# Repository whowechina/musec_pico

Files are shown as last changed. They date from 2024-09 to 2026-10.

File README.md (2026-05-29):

# Musec Pico - MUSECA Style Mini Controller
[点这里可以切换到中文版](README_CN.md)

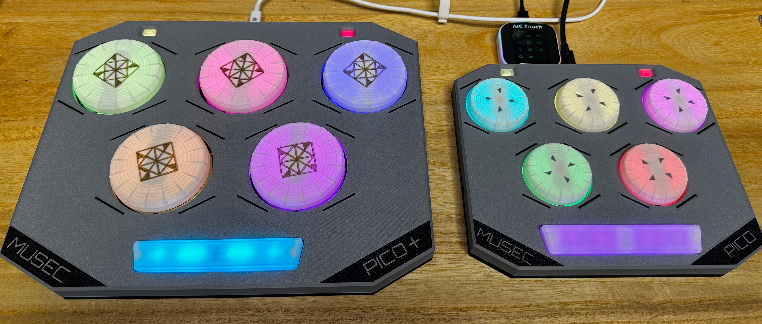
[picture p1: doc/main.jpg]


There're two versions. Musec Pico uses 52mm spinners and Musec Pico+ uses 74mm spinners. They have the same structure and function the same.

Features:
* It's small but closely replicates the feel of the arcade controller.
* Built-in "spacebar" pedal.
* External pedal support through the 3.5mm jack.
* Full HID light support.
* Command line for configurations.
* All source files open.

Thanks to many respectful guys/companies who made their tools or materials free or open source (KiCad, OnShape, InkScape, Raspberry things).

Special thanks to community projects and developers.
And also these projects:
* RP_Silicon_KiCad: https://github.com/HeadBoffin/RP_Silicon_KiCad
* Type-C: https://github.com/ai03-2725/Type-C.pretty

## My Other Projects
You can check out my other cool projects.

             

* Popn Pico: https://github.com/whowechina/popn_pico
* IIDX Pico: https://github.com/whowechina/iidx_pico
* IIDX Teeny: https://github.com/whowechina/iidx_teeny
* Chu Pico: https://github.com/whowechina/chu_pico
* Mai Pico: https://github.com/whowechina/mai_pico
* Diva Pico: https://github.com/whowechina/diva_pico
* AIC Pico: https://github.com/whowechina/aic_pico
* Groove Pico: https://github.com/whowechina/groove_pico
* Geki Pico: https://github.com/whowechina/geki_pico
* Musec Pico: https://github.com/whowechina/musec_pico
* Ju Pico: https://github.com/whowechina/ju_pico
* Bishi Pico: https://github.com/whowechina/bishi_pico
* Nos Pico: https://github.com/whowechina/nos_pico

## **Disclaimer** ##
I made this project in my personal time with no financial benefit or sponsorship. I will continue to improve the project. I have done my best to ensure that everything is accurate and functional, there's always a chance that mistakes may occur. I cannot be held responsible for any loss of your time or money that may result from using this open source project. Thank you for your understanding.

## About the License
It's CC-NC. So DIY for yourself and for your friend, don't make money from it. And plagiarism that doesn’t even dare to mention the original author is not acceptable. Plase note that pooling orders and group buying for raw materials is acceptable. Selling off any leftover components without profit is also acceptable.

If you're interested in buying from me or some kind of commercial use, please contact me (Discord, QQ group, Wechat group or leave your contact in issue section).

## My Discord Invitation
https://discord.gg/M8f2PPQFEA

## HOW TO BUILD
### PCB and Components
* Go JLCPCB and make order with the gerber zip files (latest `Production\PCB\musec_pico_xxx.zip` for Musec Pico or `Production\PCB\musec_plus_xxx.zip` for Musec Pico+, and `Procution\PCB\musec_pedal_xxx.zip` for both versions), regular FR-4 board, black or white color, **1.6mm** thickness.  
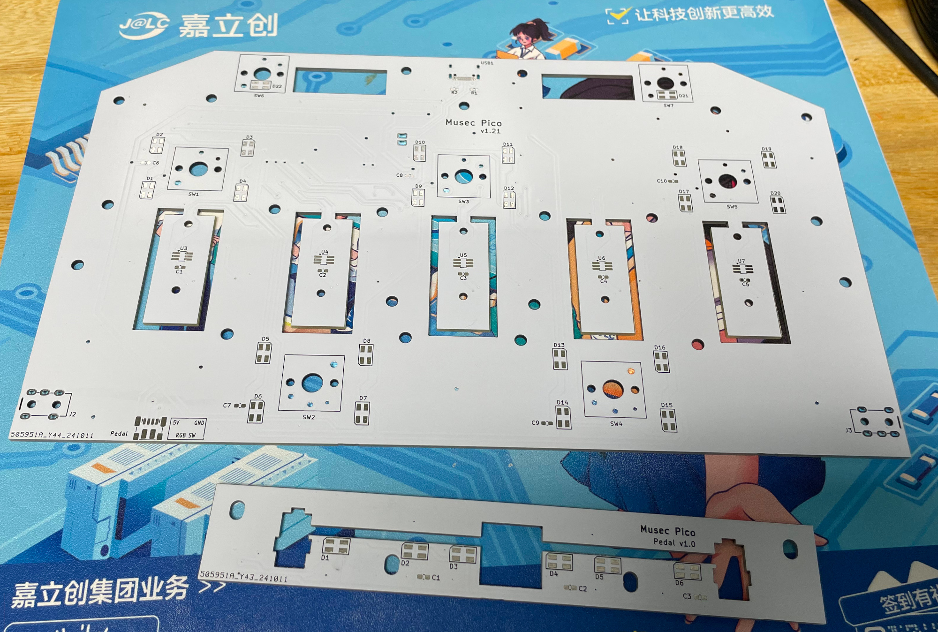
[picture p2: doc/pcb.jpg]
  
* 1x Rasberry Pico Pi Pico or pin-to-pin compatible clones (U1).  
  https://www.raspberrypi.com/products/raspberry-pi-pico
* 1x USB Type-C socket (918-418K2023S40001 or KH-TYPE-C-16P)
* 28x WS2812B-3528 RGB LEDs (all RGB LEDs).
* 6x TMAG5273, all device versions (such as A1, B2, etc.) works, SOT23-6 (U3 to U7).  
* 12x 0603 0.1uF (0.1~1uF all fine) capacitors (all Capacitors).
* 2x 0603 5.1kohm resistors (R1, R2) for the USB.
* 2x 0603 5.1kohm resistors (R3, R4, 1k-20kohm all work fine) for I2C pull-up.
* 2x PJ-313 through-hole 3.5mm audio jacks (J2, J3).  
* 12x JST-SH1.0 4-pin right angle SMD connectors (JA1 to JA5, JB1 to JB5, Pedal, J1 on pedal board).  
  https://www.amazon.com/Kidisoii-Connector-Mounting-Vertical-SH1-0-SMT-Ver/dp/B0CQ28CCQG?th=1
* 6x JST-SH1.0 dual-end 4-pin cables, 60mm length * 5, and 100mm length * 1.
   The connector footprint on PCB also supports hand soldering. So if you can't find the connectors or the cables, you can solder the wires directly to the PCB.  
   RC hobby sites often have SH1.0 4P silicone cables, but with only one end connector. You can solder the other end to the PCB. It's still a good choice.
* 7x Kailh Choc v1. Choose heavy ones (70gf), I think the yellow with 70g force is the best.  
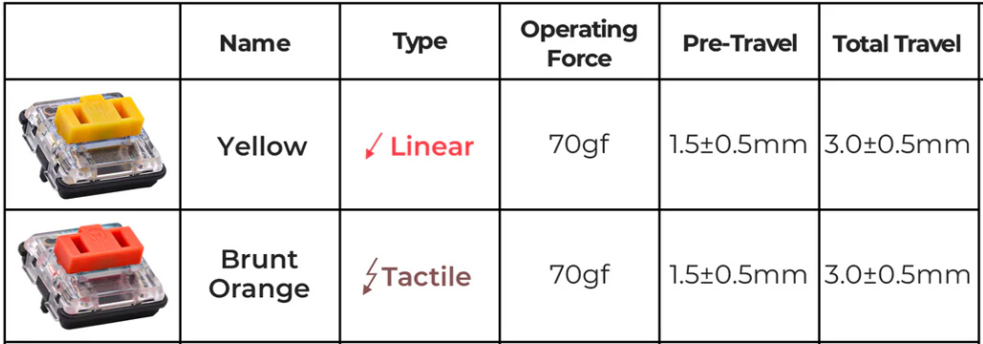
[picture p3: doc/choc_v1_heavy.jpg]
  
* For Musec Pico+, you can use one switch per button, or 2x switches per button to get more force.  
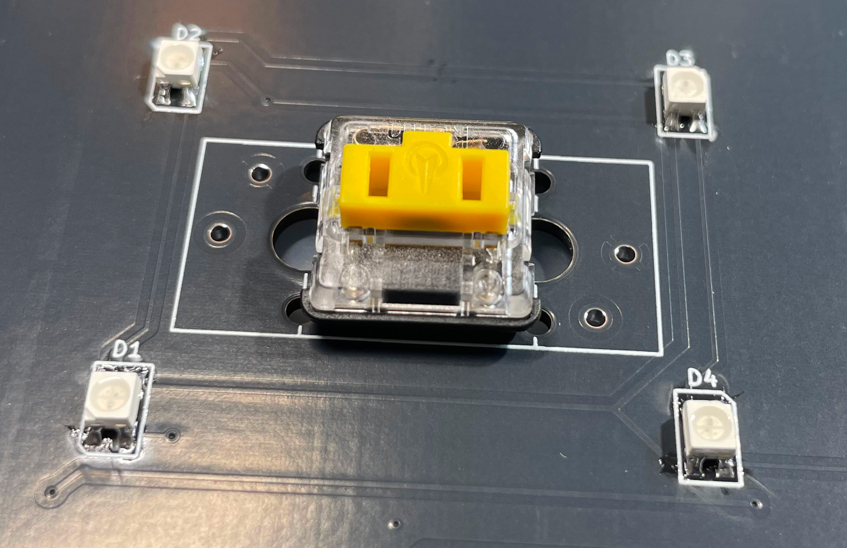
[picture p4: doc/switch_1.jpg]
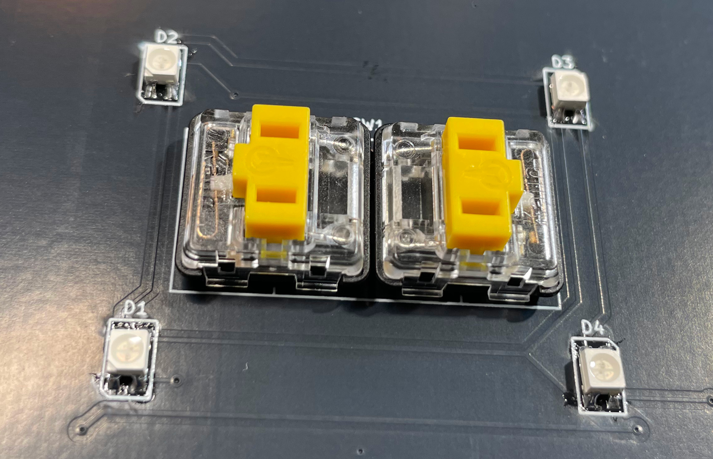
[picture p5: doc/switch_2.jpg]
   
* 1x MX-compatible switch, I personally use Gateron POM CJ BOX.
* 1x Plate-mounting stabilizer for the MX switch, 6.25U.  
  https://www.amazon.com/GATERON-Stabilizer-Mechanical-Keyboard-Satellite/dp/B0C137DG5Q/

* This is how it looks after soldering (there might be changes in newer versions of PCB). I'm only showing the Musec Pico, but the Musec Pico+ is similar.  
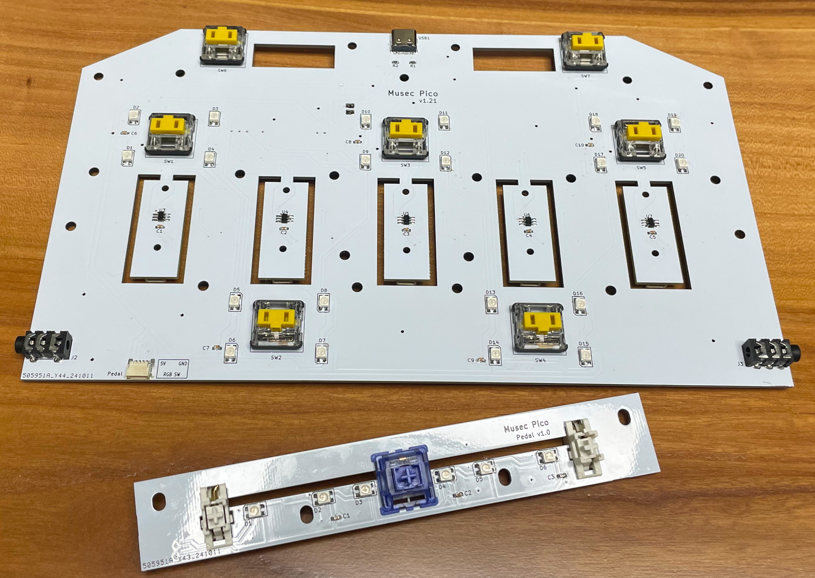
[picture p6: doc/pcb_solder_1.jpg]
    
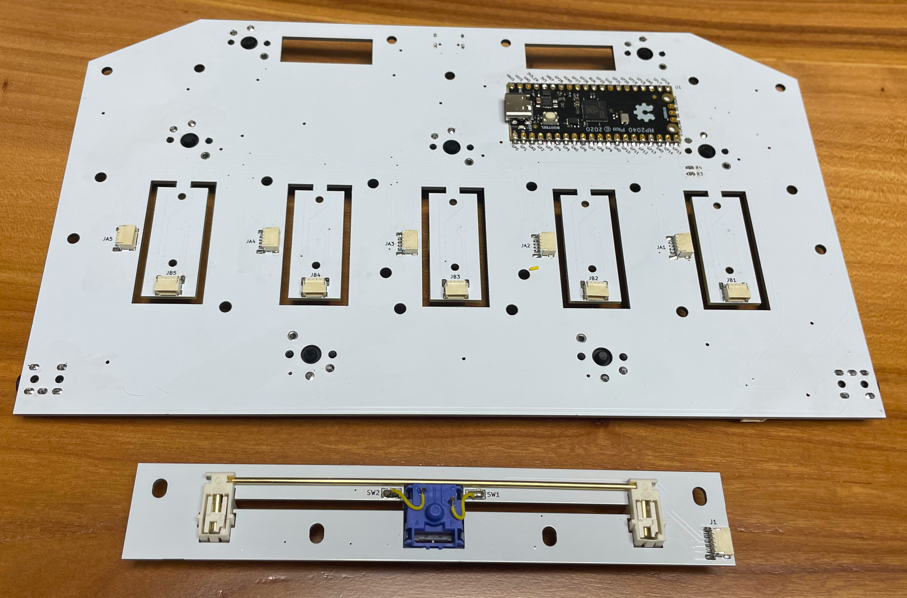
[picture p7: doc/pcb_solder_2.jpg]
  
* Becareful of 2 pin holes. It's a common oversight to either forget to solder them or to leave air bubbles during the process. To avoid this, solder slowly from one side of the hole, using minimal solder wire and a generous amount of flux.  
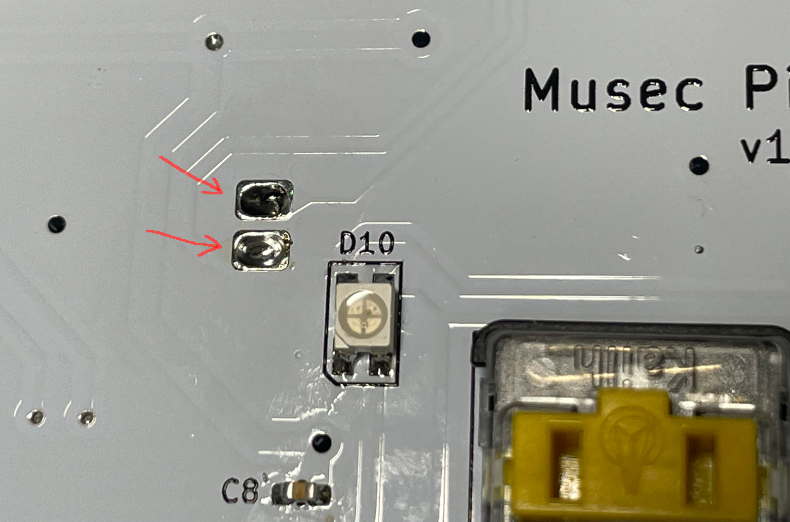
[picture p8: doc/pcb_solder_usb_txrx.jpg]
  

### Test the PCB
* You can test the PCB now, put the firmware in.
* All RGB LEDs should light up in a rainbow pattern.
* LEDs responds to the button presses.
* Musec Pico should be recognized as a USB HID device, here's the test page.  
  https://greggman.github.io/html5-gamepad-test/
* Move a magnetic screwdriver tip close to the TMAG5273 sensor, you'll notice the corresponding axis move in the test page. Please check all 5 sensors.

### Sensor PCB Separation
* If everthing works fine, you can cut off (or even bend and snap) the 5 small sensor boards from the main board.  
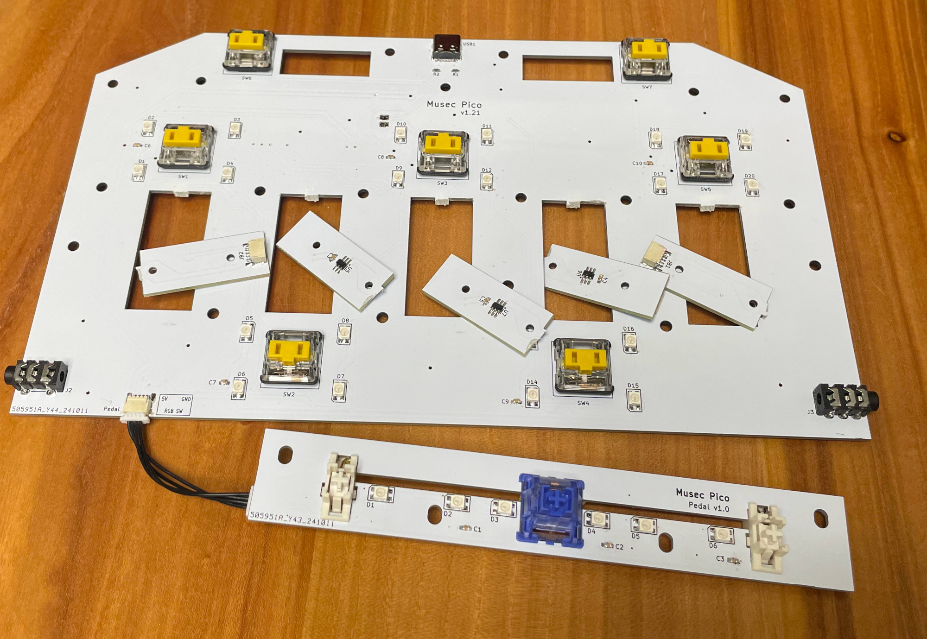
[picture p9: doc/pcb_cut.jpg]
  

### 3D Printing
The following descriptions are for Musec Pico. If you're making Musec Pico+, please find the corresponding files with `+` in the name.

#### Printing parameters  
* PLA or PETG.
* Layer height: 0.2mm
* Support: Yes, always.
* Glue on bed: Yes, it prevents corner warping.
* Files are always in milimeter unit, not inch.

#### 5x Spinner Parts
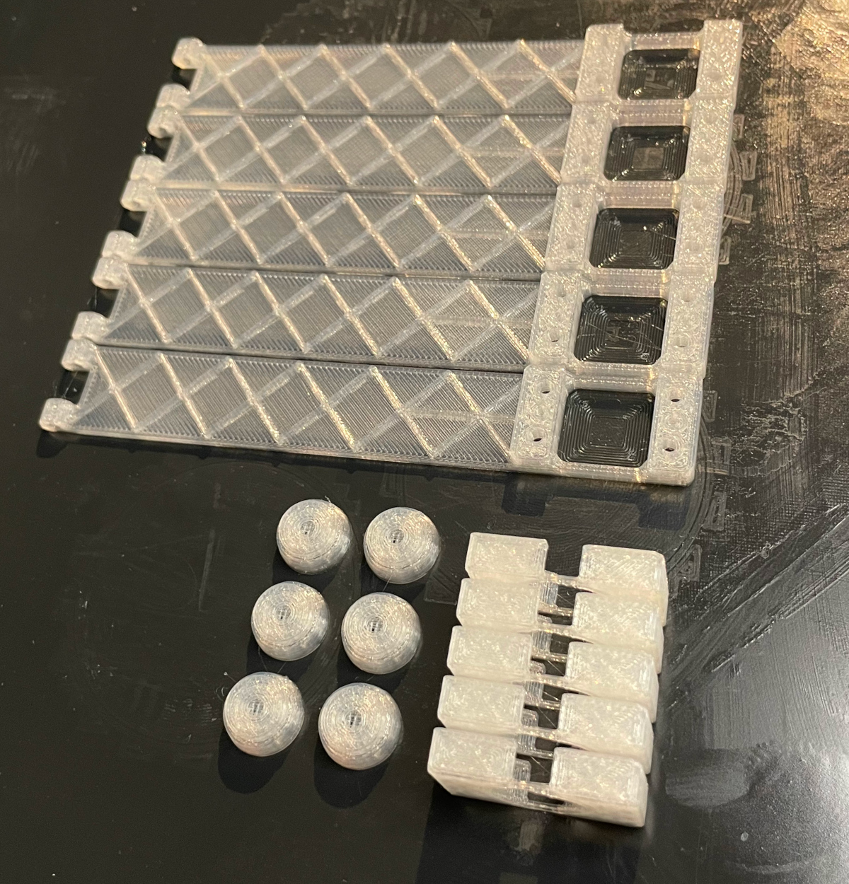
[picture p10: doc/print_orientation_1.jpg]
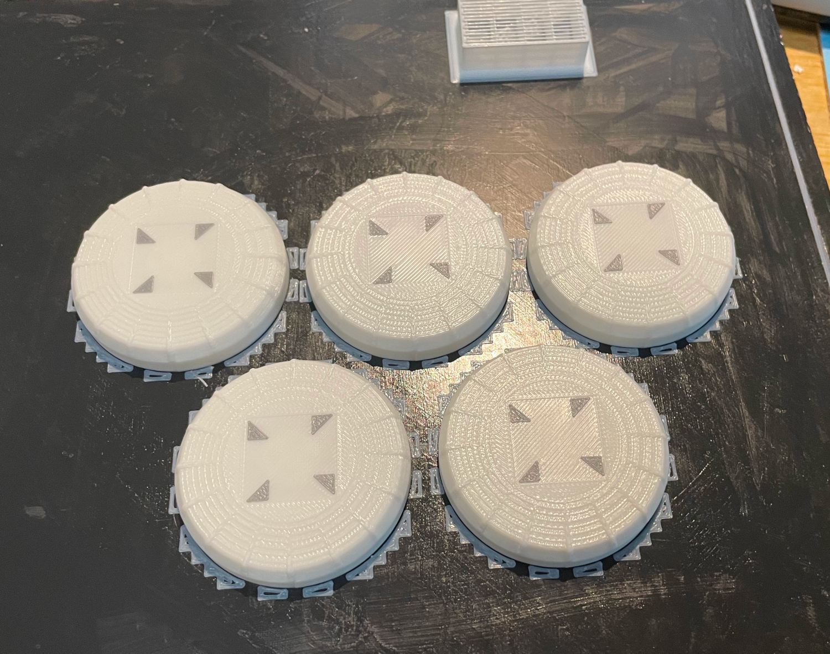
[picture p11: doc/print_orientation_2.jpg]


* Keycap: `Production\3DPrint\musec_pico_keycap.stl`, white, 5 walls or >=90% infill. If you have multi-color system, print the 4 triangle marks on the top in gray. 
* Bearing Fixer: `Production\3DPrint\musec_pico_bearing_fixer.stl`, clear transparent.
* Shaft End: `Production\3DPrint\musec_pico_shaft_end_xxx.stl`, clear transparent, choose the one matches your magnet size.
* Lever: `Production\3DPrint\musec_pico_lever.stl`, clear transparent.
* Pad: `Production\3DPrint\musec_pico_pad.stl`, white, gray or black (so it won't affect the LED color).

#### Housing Parts
* Housing Bottom: `Production\3DPrint\musec_pico_bottom.stl`, black, use special support material for nicer screw hole surface.
* Housing Top: `Production\3DPrint\musec_pico_top.3mf`, gray, print up-side-down. If you have multi-color system, print the logo and lines in black.

#### Other Parts
Musec Pico and Musec Pico+ share these parts.
* Pedal: `Production\3DPrint\musec_pico_pedal.stl`, white, print upside down.
* Aux Buttons: `Production\3DPrint\musec_pico_aux.stl`, clear transparent, print upside down.

### Assembly
The following descriptions are for Musec Pico. But Musec Pico+ has the same internal structure, so the assembly is similar.

#### Other components needed
* **M2.5\*6mm screws** (5x for Musec Pico, 15x for Musec Pico+) for fixing the keycap to the bearing.
* 30x **M2\*8mm screws** for fixing the bearing and the sensor PCB to the lever.
* 15x **M3\*8mm screws** for fixing button pads to the bottom housing.
* 16x **M3\*(10-12mm) screws** for fixing the top and bottom housing and the pedal board to the bottom housing.  
* 5x 6700zz (10x15x4mm for Musec Pico), or 6702zz (15x21x4mm, for Musec Pico+) bearings for the spinner, just buy cheapest ones. They may come packed with a heavy weight oil that arrests rotation, this can be corrected by thoroughly degreasing the bearings and relubricating them with a lightweight oil like Super Lube ISO 68. For example, a soak and spin in 99% isopropyl alcohol, dry on a heated plate to remove the excess alcohol and thin and remaining grease, then a final wash in acetone (if you have all-metal bearings) and additional heated dry before relubricating will ensure the bearings spin freely.
  https://www.amazon.com/uxcell-6700ZZ-Groove-Bearings-Shielded/dp/B082PPYZQX/
* 5x round magnets, 5-7mm diameter for Musec Pico, 5mm only for Musec Pico+, 3mm or 4mm also works if you stick it well, 1.5mm or 2mm tall, MUST be radially/diametrically magnetized (N-S poles on the curved side).  
  https://wargameportal.com/products/special-diametrically-magnetized-50pcs-5mm-x-2mm-3-16-x-1-16-disc-magnets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
* 5x 2mm diameter steel shafts for the lever, 25mm length for Musec Pico, 40mm length for Musec Pico+.
* For Musec Pico+, you can use 5x 0.4mm\*5mm\*10mm\*6N (wire diameter\*outer diameter\*length\*number of coils) springs to increase the button force.  
* Some good tape (such as acetate tape or high-temp teflon tape) to fix the magnets in place.
* PTFE or UHMW tape for the sliding surfaces.
* Silicone anti-slip pads for the bottom.  
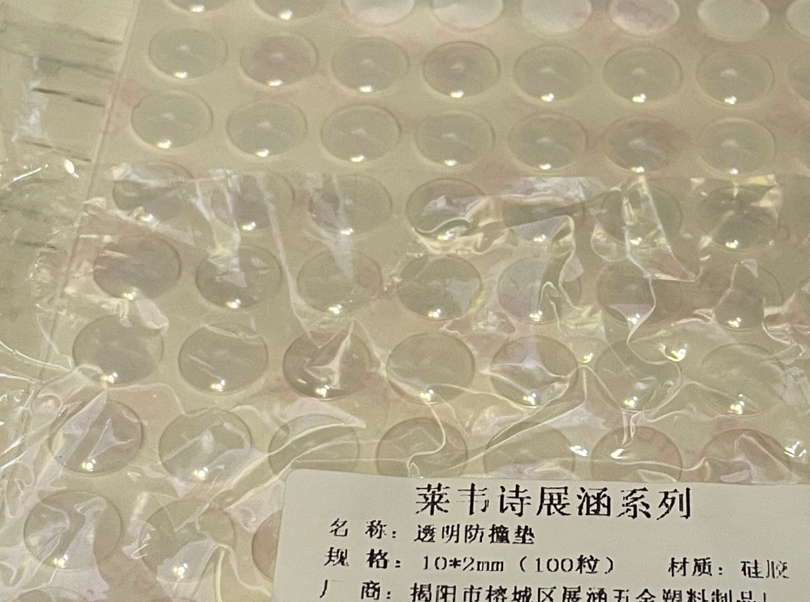
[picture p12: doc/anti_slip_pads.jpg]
  
* Optional but good to have: plastic washer (ring pads), 0.5mm thick, 2.1~2.5mm inner diameter, 5-10mm outer diameter.  
  https://www.amazon.com/Bclla-Zkenshan-washers-Shock-Proof-Leak-Proof-Insulation/dp/B091Y7H9NX/
* Optional but good to have: A digital piano or music keyboard sustain pedal or a sewing machine pedal with 3.5mm jack. If it comes with 6.25mm jack, you also need a 6.25mm to 3.5mm adapter.

#### Steps
1. We'll start with the spinner part.  
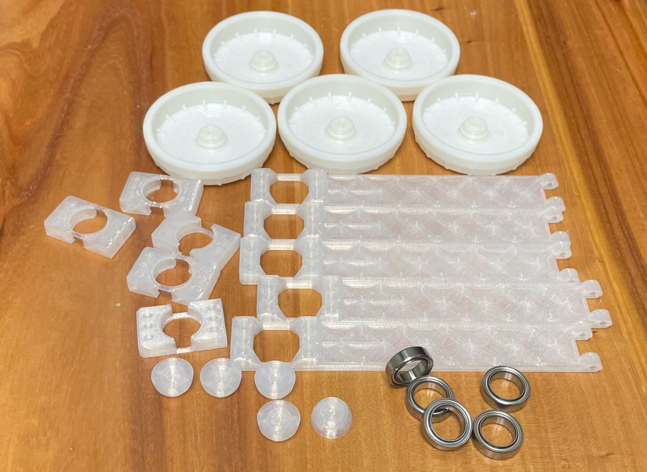
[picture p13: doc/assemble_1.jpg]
   

2. Put the bearing into the bearing fixer, you'll need to bend the fixer a little bit to insert the bearing. Don't worry if the small connection part of the fixer breaks, it's fine. Then screw the bearing fixer to the lever.  
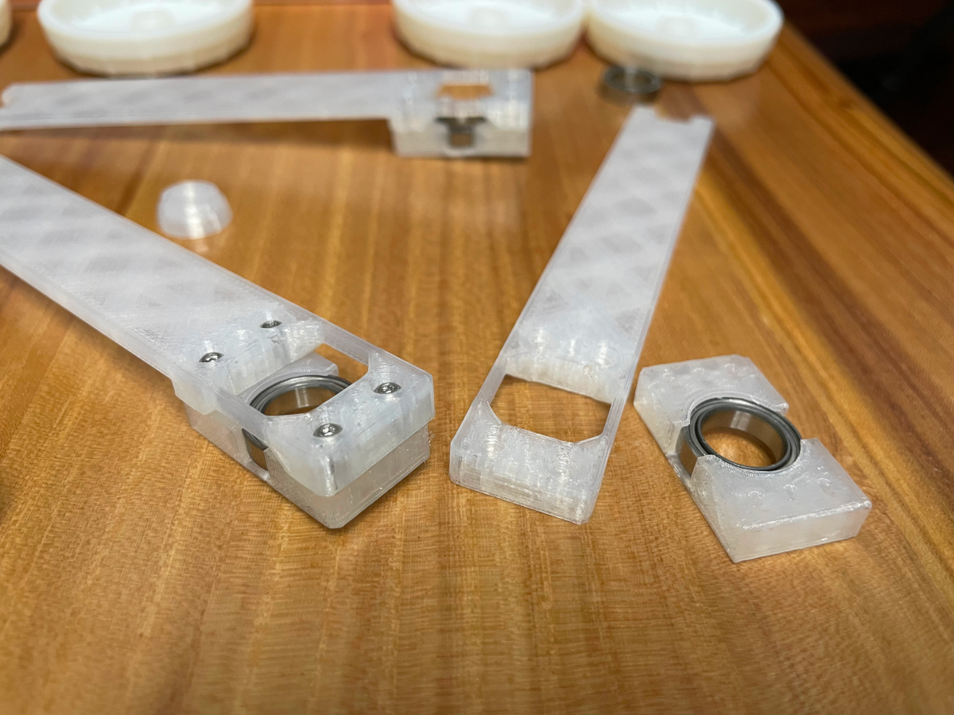
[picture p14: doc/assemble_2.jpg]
   

3. Screw the keycap using M2.5 screws mentioned earlier.  
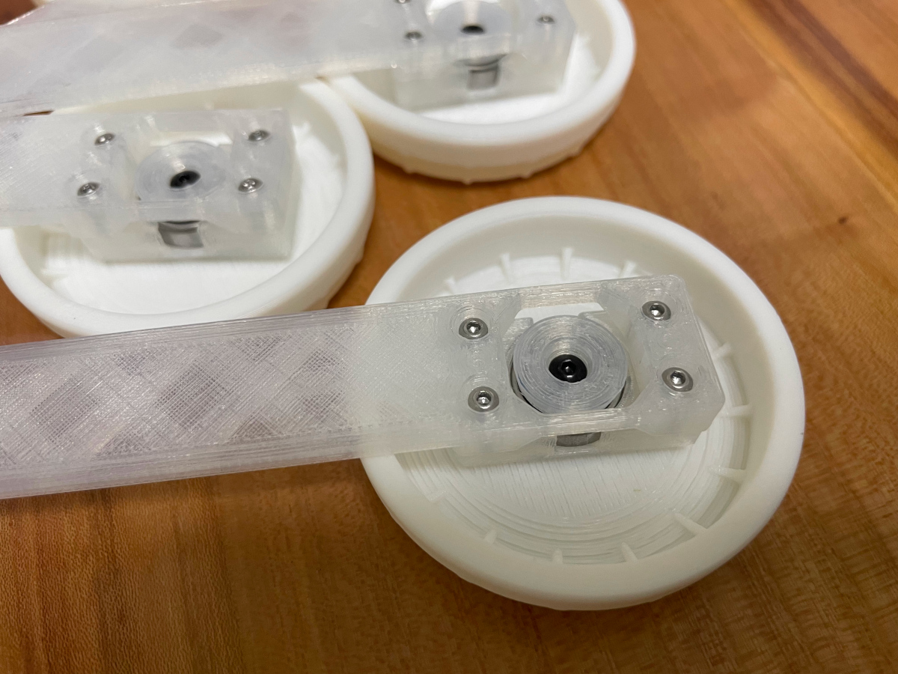
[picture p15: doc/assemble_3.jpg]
   

4. Now insert the magnet into the slot at the center. It will be attracted to the screw head. But we still need some tape to fix it in place.  
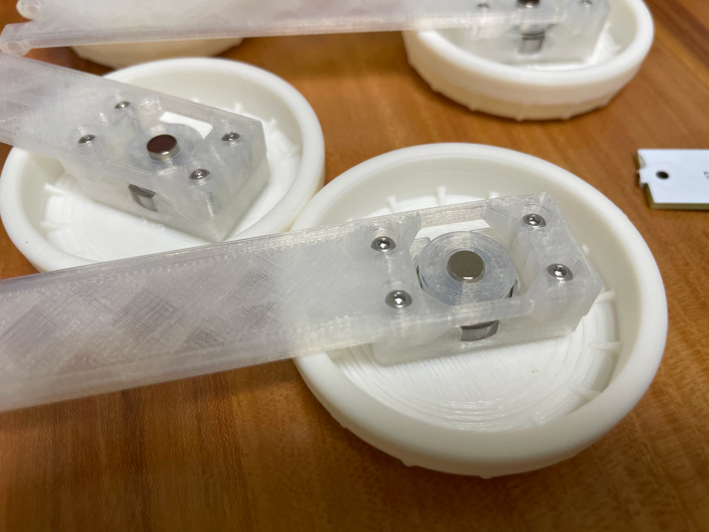
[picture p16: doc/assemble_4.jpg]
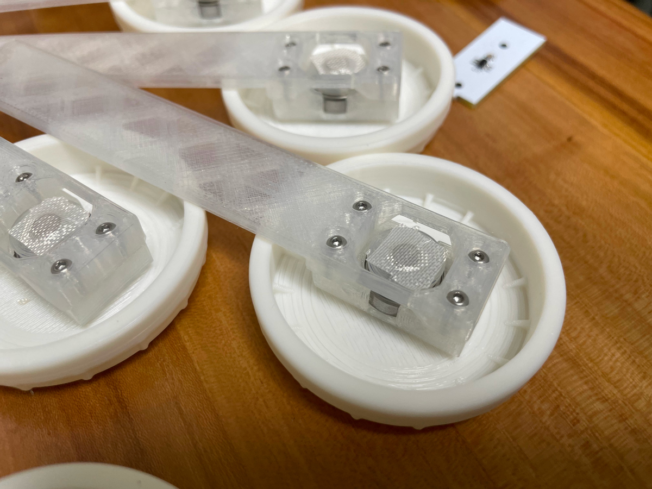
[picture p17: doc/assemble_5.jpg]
   

5. Screw the sensor PCB to the lever and put a small piece of thin PTFE/UHMW tape on the surface. And lastly insert the shaft into the lever.  
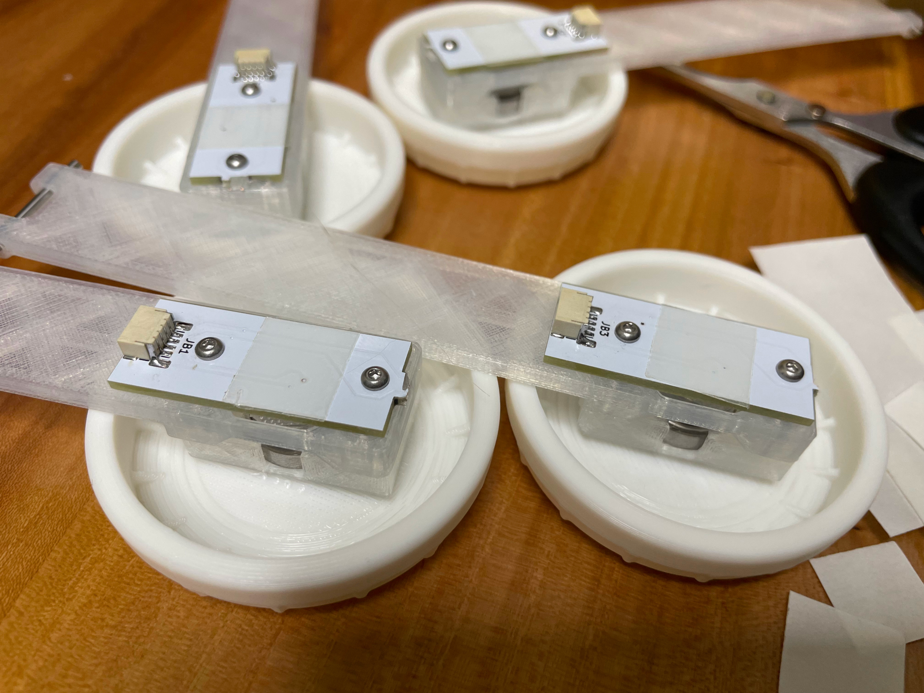
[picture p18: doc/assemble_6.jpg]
   

6. Connect 5 SH1.0 cables to the main PCB. Install the main PCB and the pedal PCB to the bottom housing. Use another SH1.0 cable to connect the pedal PCB and the main PCB. The screwholes on pedal board is adjustable. Normally you need to install the pedal board a little higher.    
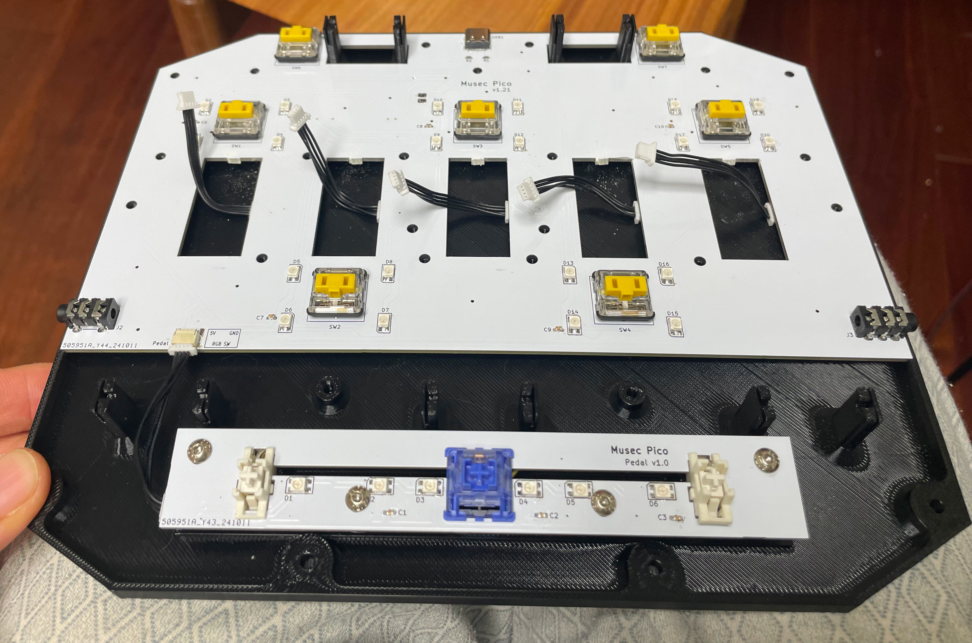
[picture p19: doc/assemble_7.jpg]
   

7. Connect the SH1.0 cables which are already connected to the main board to the sensor PCBs. And then push the lever shafts into the stands on the bottom housing. If you have keyboard lubricant, you can apply some to the shaft and the stand.  
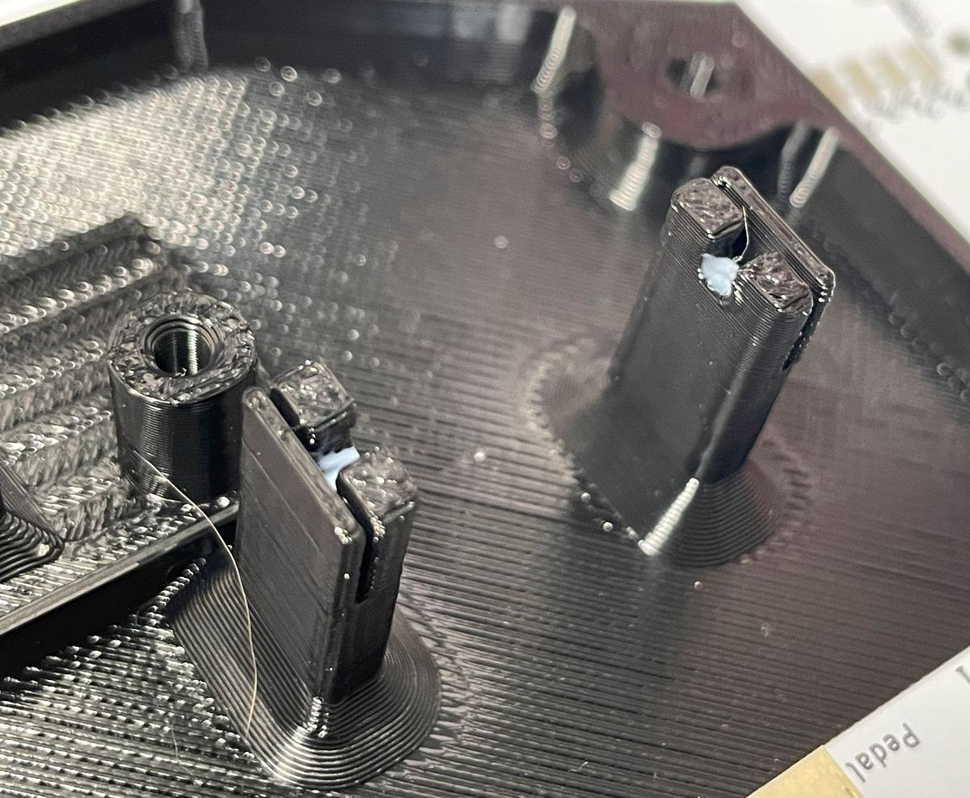
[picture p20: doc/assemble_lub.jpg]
     
   A pair of plastic washer will be helpful to prevent the lever from moving. They can also be used to adjust the lever position, compensating for the printing tolerance.  
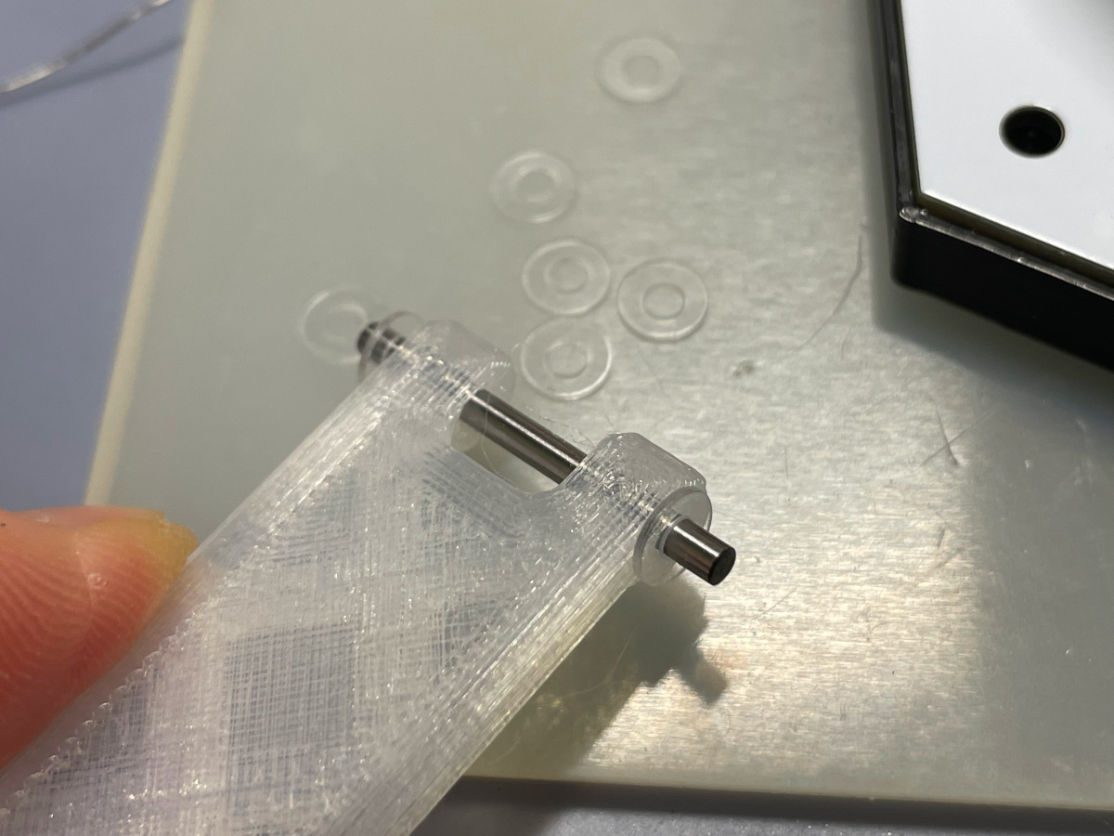
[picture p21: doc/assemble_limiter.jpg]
     
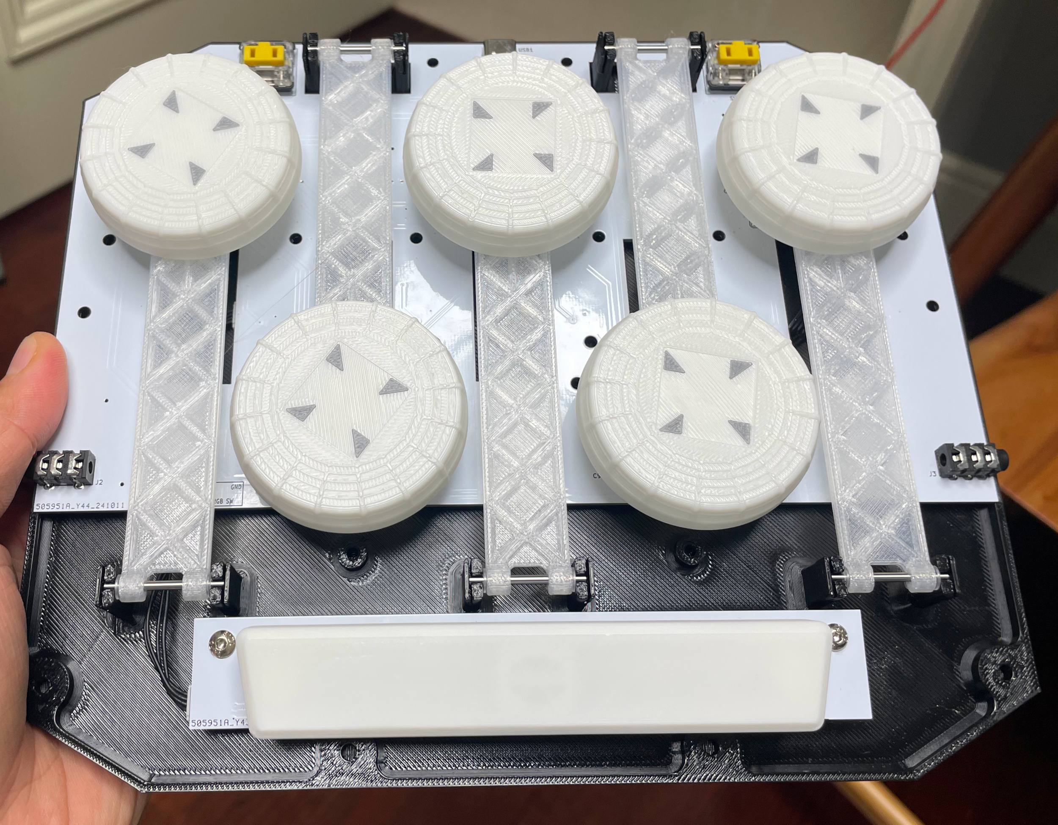
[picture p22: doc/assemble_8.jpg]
   

8. Install the button pads using M3*8mm screws.  
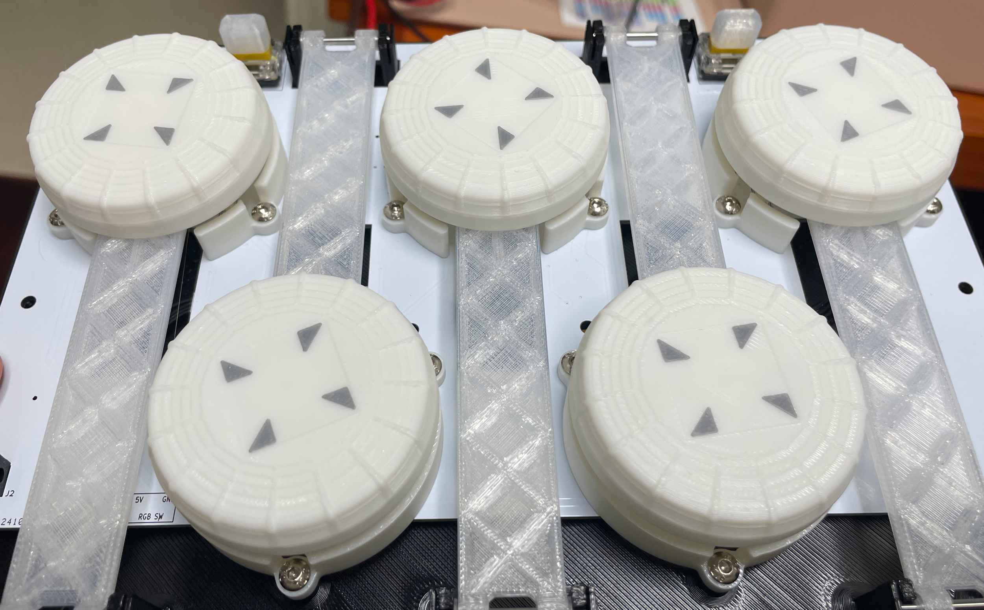
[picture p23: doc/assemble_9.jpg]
   

9. Only for Musec Pico+, you can put springs onto the spring seats.

10. Install the top housing, you need to screw many M3 screws.  
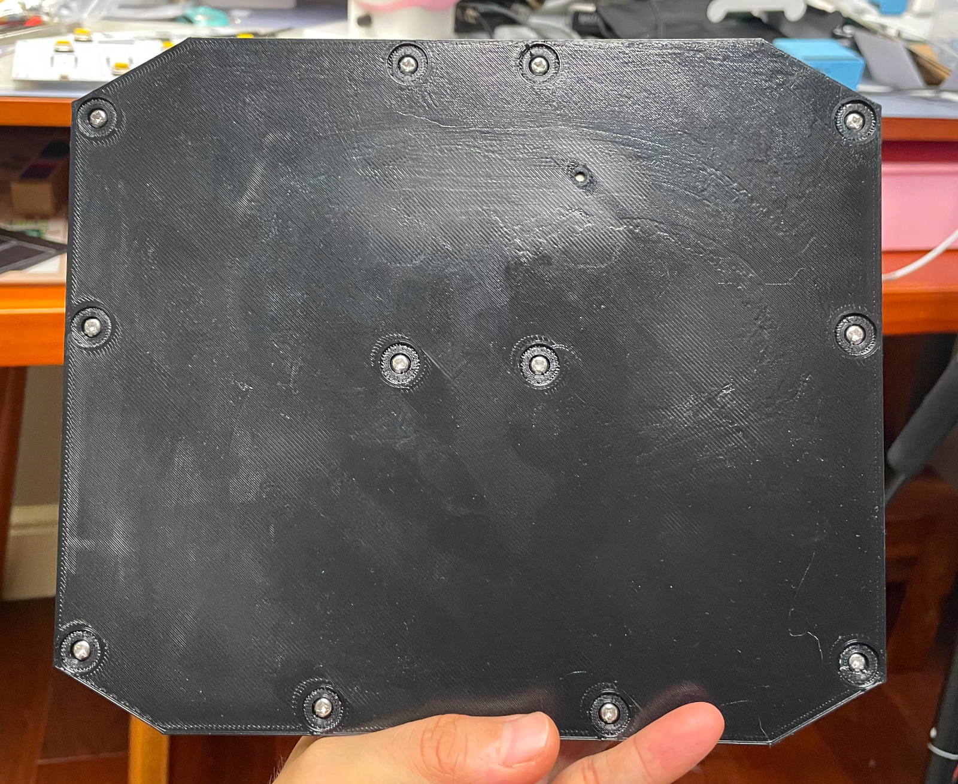
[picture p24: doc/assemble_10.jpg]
   

11. Put the anti-slip pads on the bottom, right on top of the screws.  

#### Caution
* Each 3D printer and filament has its own tolerance. If you find the stem holes on the pedal keycap are too tight, use some needle or knife to enlarge them a little bit.
* Screws are easy to break the 3D printed parts. So don't screw them too tight. When you notice the resistance suddenly increases, stop screwing.

### Firmware
* UF2 file is in `Production\Firmware` folder.
* For the new build, hold the BOOTSEL button while connect the USB to a PC, there will be a disk named "RPI-RP2" showed up. Drag the UF2 firmware binary file into it. That's it. There's a small hole at the bottom side of the Musec Pico, it is facing right to the BOOTSEL button.
* If it's already running Musec Pico firmware, you can either use "update" in command line or hold down at least 4 buttons while connecting to USB to enter update mode.
* To access the command line, you can use this Web Serial Terminal to connect to the USB serial port of the Musec Pico. (Note: "?" is for help)  
  https://googlechromelabs.github.io/serial-terminal/

### Usage
* It's very simple. Just plug it in and play.
* You can set spin sensivity by "spin rate" command.
* Firmware identifies the polarity of the external pedal on power-up. Press Aux and Internal Pedal to re-identify the polarity.

## CAD Source File
I'm using OnShape free subscription. It's powerful but it can't archive original designs to local, so I can only share the link here. STL/DXF/DWG files are exported from this online document.  
  https://cad.onshape.com/documents/841383e62eb719d8b384c2c8/w/8c9b3131eb80c219de824619/e/8a5d9f0dffe483e0bce3630a

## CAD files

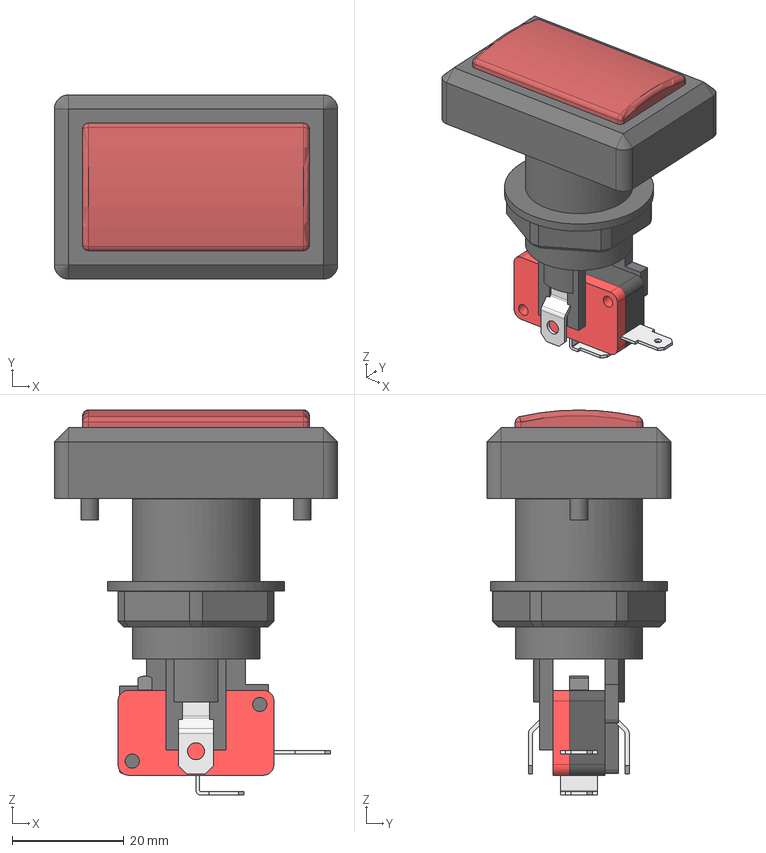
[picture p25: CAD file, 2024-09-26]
PCB/plus/3dmodels/Credit Button Assy (Groovy).step
50.8 x 33.0 x 69.0 mm
Button
Nut
Switch

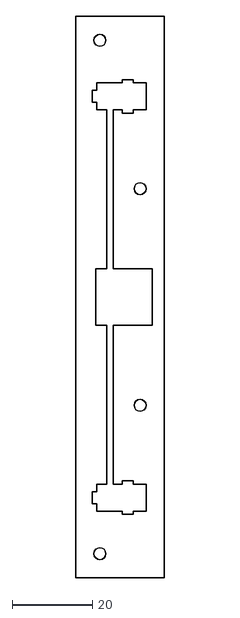
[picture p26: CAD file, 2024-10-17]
PCB/pedal/Button_Pedal - PCB.dxf
22.0 x 140.0

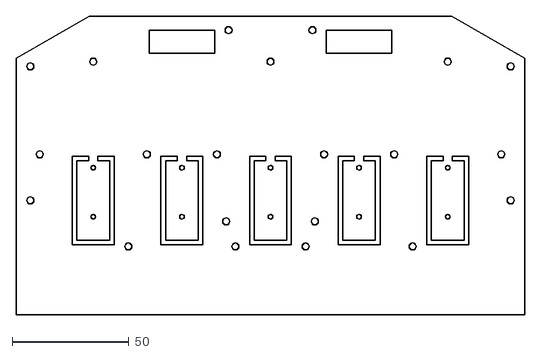
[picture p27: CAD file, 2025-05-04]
PCB/pico/Housing - PCB.dxf
218.0 x 128.1

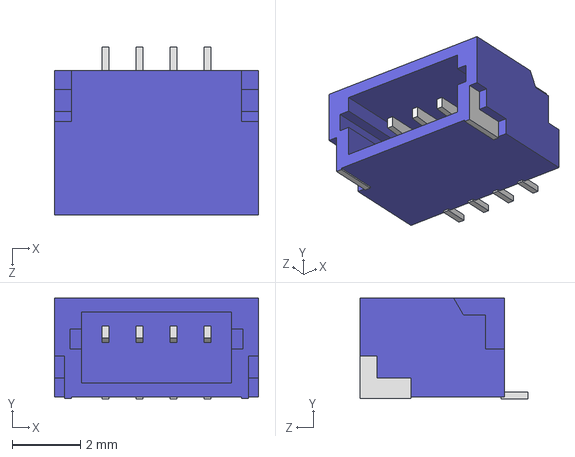
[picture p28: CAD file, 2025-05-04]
PCB/plus/3dmodels/SM04B-SRSS-TB.STEP
6.00 x 2.96 x 4.95 mm

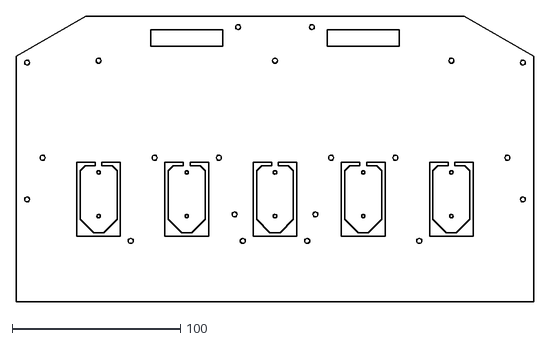
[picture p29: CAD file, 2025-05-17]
PCB/plus/Musec Pico+ - PCB.dxf
308.0 x 170.0

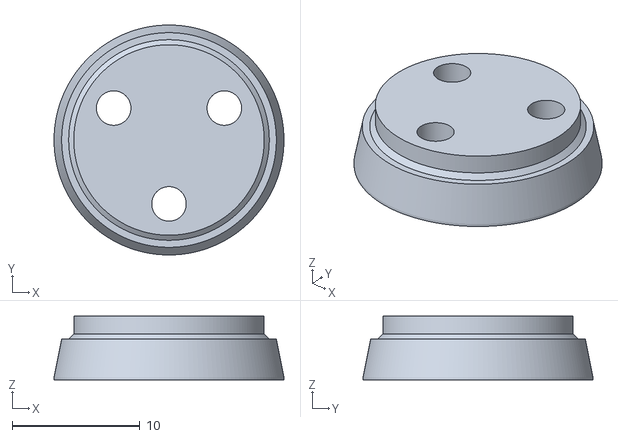
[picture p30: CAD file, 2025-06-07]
Production/3DPrint/musec_pico+_shaft_end_5mm.stl
18.0 x 18.0 x 5.00

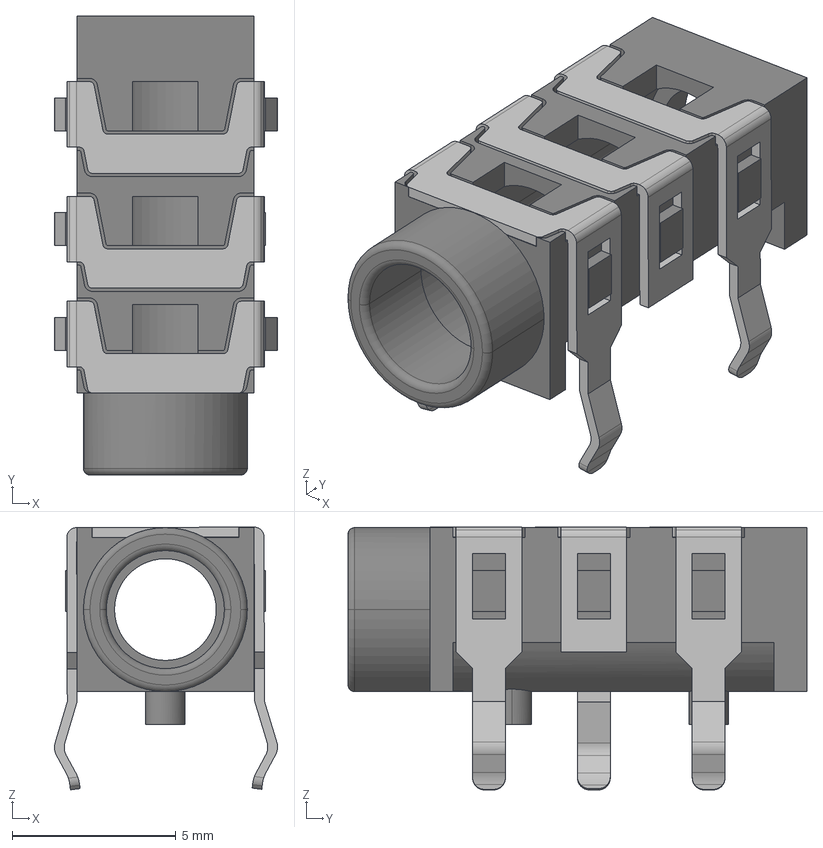
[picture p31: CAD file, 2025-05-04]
PCB/plus/3dmodels/TRS Jack PJ-313.stp
6.81 x 14.0 x 8.02 mm

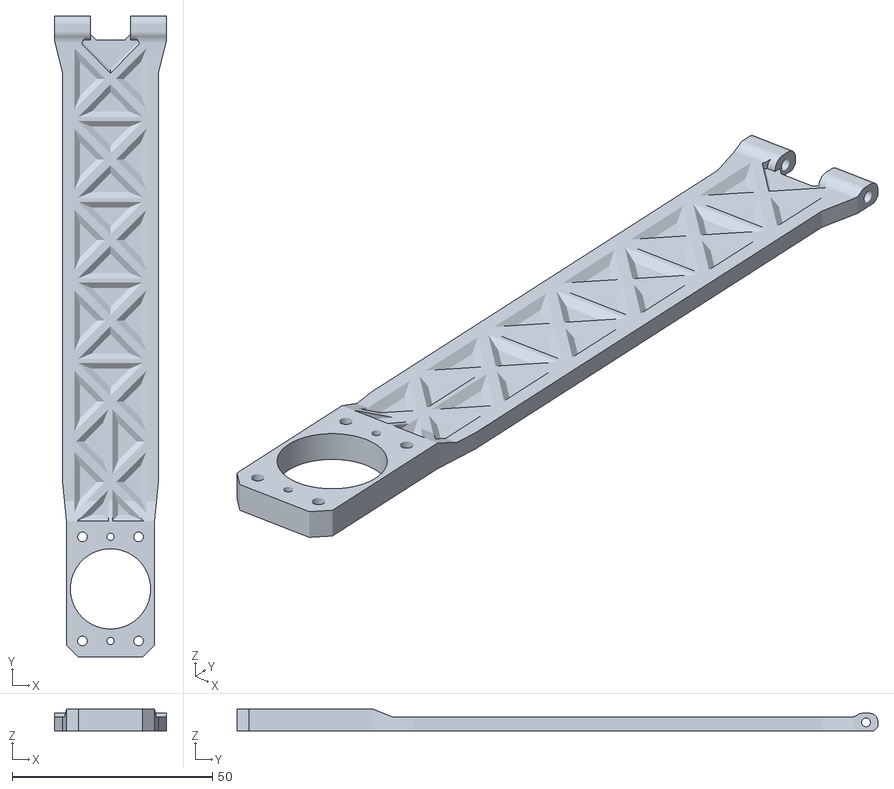
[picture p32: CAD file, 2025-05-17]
Production/3DPrint/musec_pico+_lever.stl
28.0 x 160.0 x 5.40

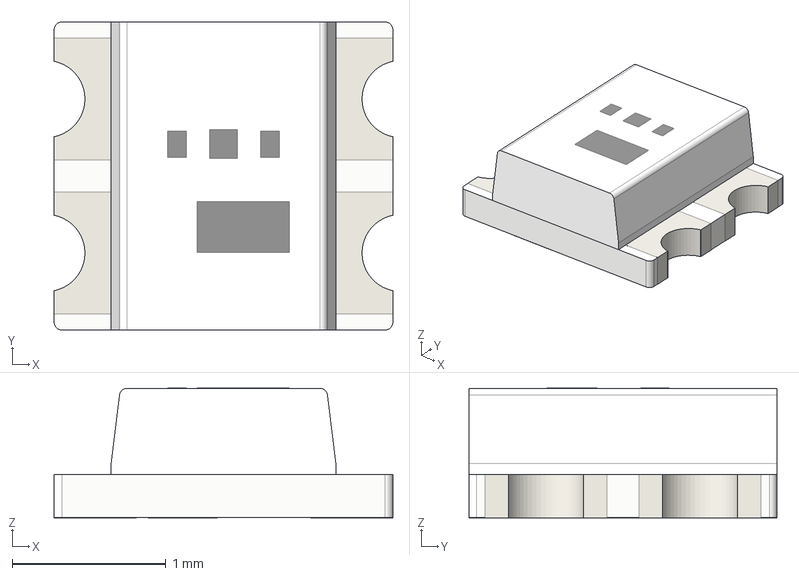
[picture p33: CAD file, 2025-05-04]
PCB/plus/3dmodels/LED_WS2812_2020.step
2.20 x 2.00 x 0.842 mm

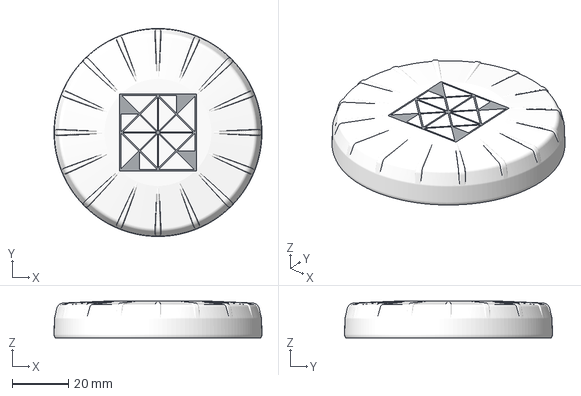
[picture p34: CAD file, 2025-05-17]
Production/3DPrint/musec_pico+_keycap.3mf
73.9 x 73.9 x 13.0 mm
Keycap
Pattern

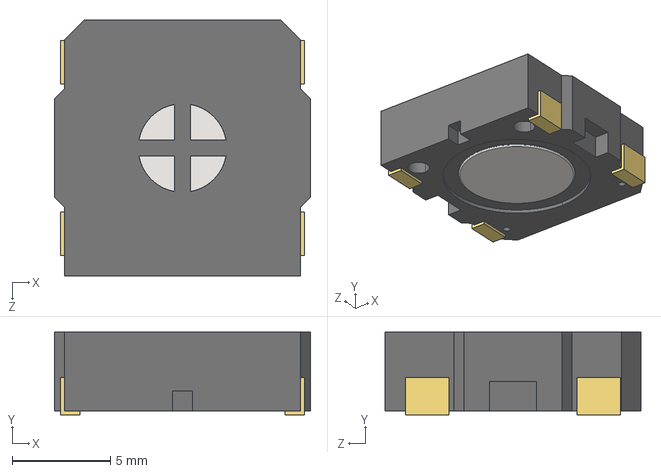
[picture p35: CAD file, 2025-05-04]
PCB/plus/3dmodels/SPEAKER_SMD_1340.STEP
13.0 x 4.20 x 13.0 mm

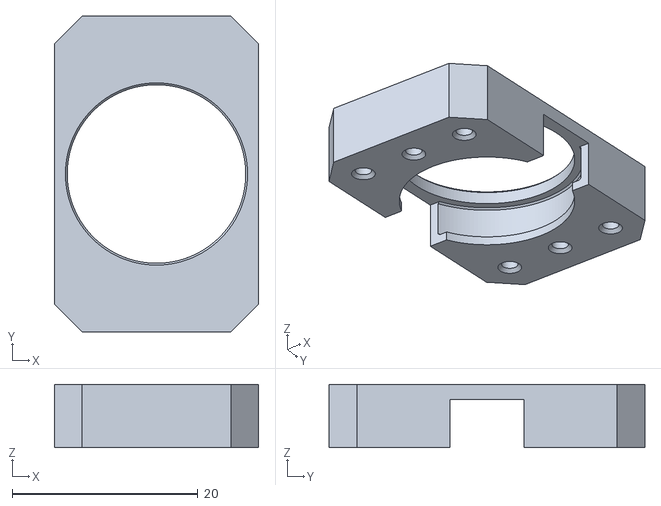
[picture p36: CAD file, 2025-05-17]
Production/3DPrint/musec_pico+_bearing_fixer.stl
22.0 x 34.0 x 6.80

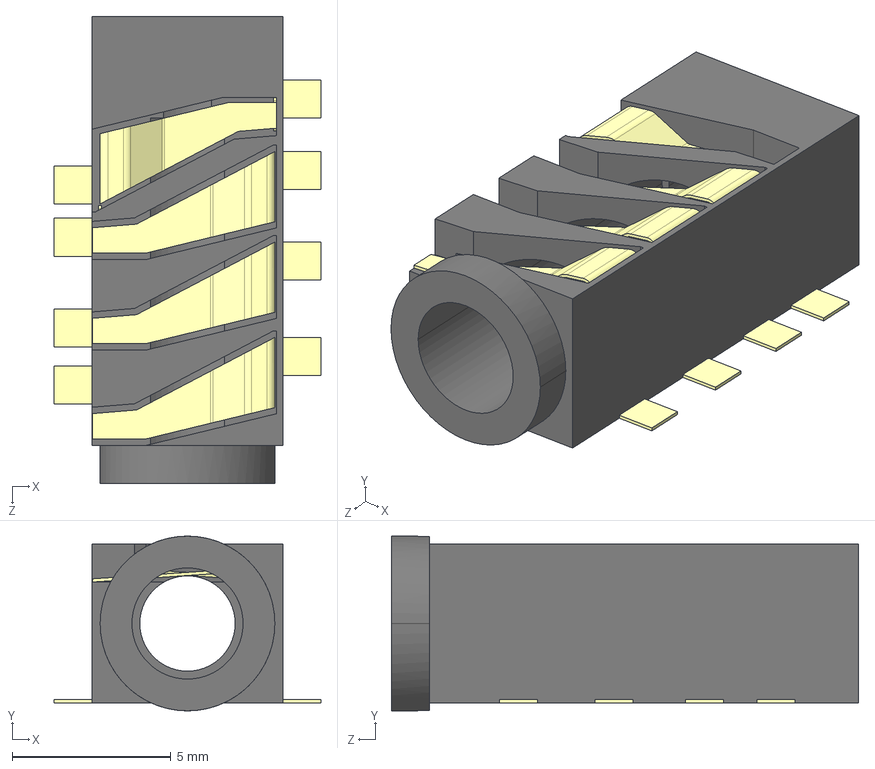
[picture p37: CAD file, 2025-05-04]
PCB/plus/3dmodels/User Library-pj-393-8.STEP
8.40 x 5.50 x 14.7 mm
PJ-393-8_1
PJ-393-8_2 x 4
PJ-393-8_3
PJ-393-8_4 x 3

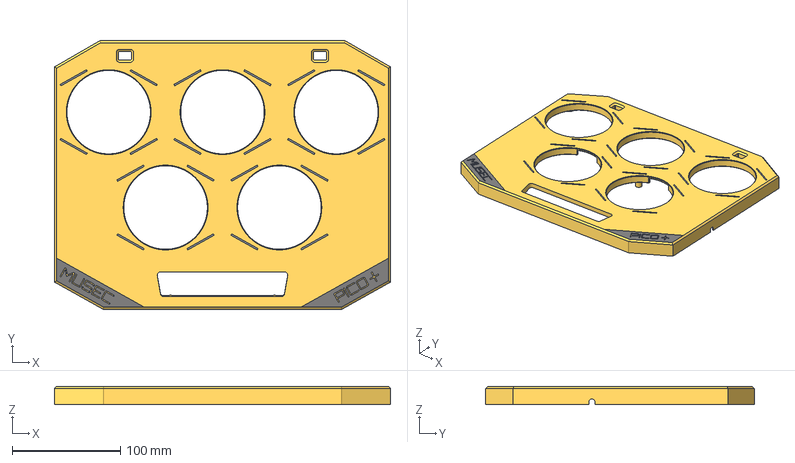
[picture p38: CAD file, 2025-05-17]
Production/3DPrint/musec_pico+_top.3mf
310.0 x 248.0 x 17.0 mm
Top
Logo_1
Logo_2
Logo_3
Logo_4

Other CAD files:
PCB/plus/3dmodels/iidx_keycap_main_step.stp
PCB/plus/3dmodels/SKRRABE010.stp
Production/3DPrint/musec_pico+_pad.stl
Production/3DPrint/musec_pico_bottom.stl
PCB/plus/3dmodels/gp2y0e03.scad
PCB/plus/3dmodels/keypad_lgp.scad
PCB/plus/3dmodels/530470310.stp
PCB/plus/3dmodels/8002A.step
PCB/plus/3dmodels/Button Cap.step
PCB/plus/3dmodels/EVQ-P1D05M.stp
PCB/plus/3dmodels/FPC0.5MM1.0H18P.step
PCB/plus/3dmodels/Geki_Slider.step
PCB/plus/3dmodels/J 2835.step
PCB/plus/3dmodels/Kailh LP Choc PC Keycap.step
PCB/plus/3dmodels/Kailh_PG1353.STEP
PCB/plus/3dmodels/Magnetic Pogo Connector 5 Pin (F).STEP
PCB/plus/3dmodels/Magnetic Pogo Connector 5 Pin (M) - 副本.STEP
PCB/plus/3dmodels/Magnetic Pogo Connector 5 Pin (Type 1).STEP
PCB/plus/3dmodels/Magnetic Pogo Connector 5 Pin (Type 2).STEP
PCB/plus/3dmodels/Magnetic Pogo Connector 5 Pin (Type 3).STEP
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

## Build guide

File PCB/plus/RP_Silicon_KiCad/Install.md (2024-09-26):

# Install KiCad libraries

## Manage Symbol Libraries

Accessed from the Preferences menu, add a new line with the +, give it a name and use the folder icon to point to the directory/folder where you have KiCadLibraries.

Manage Symbol Libraries screen shot


## Manage Footprint Libraries

Ditto! Accessed from the Preferences menu, add a new line with the +, give it a name and use the folder icon to point to the directory/folder where you have KiCadLibraries.

Manage Footprint Libraries screen shot


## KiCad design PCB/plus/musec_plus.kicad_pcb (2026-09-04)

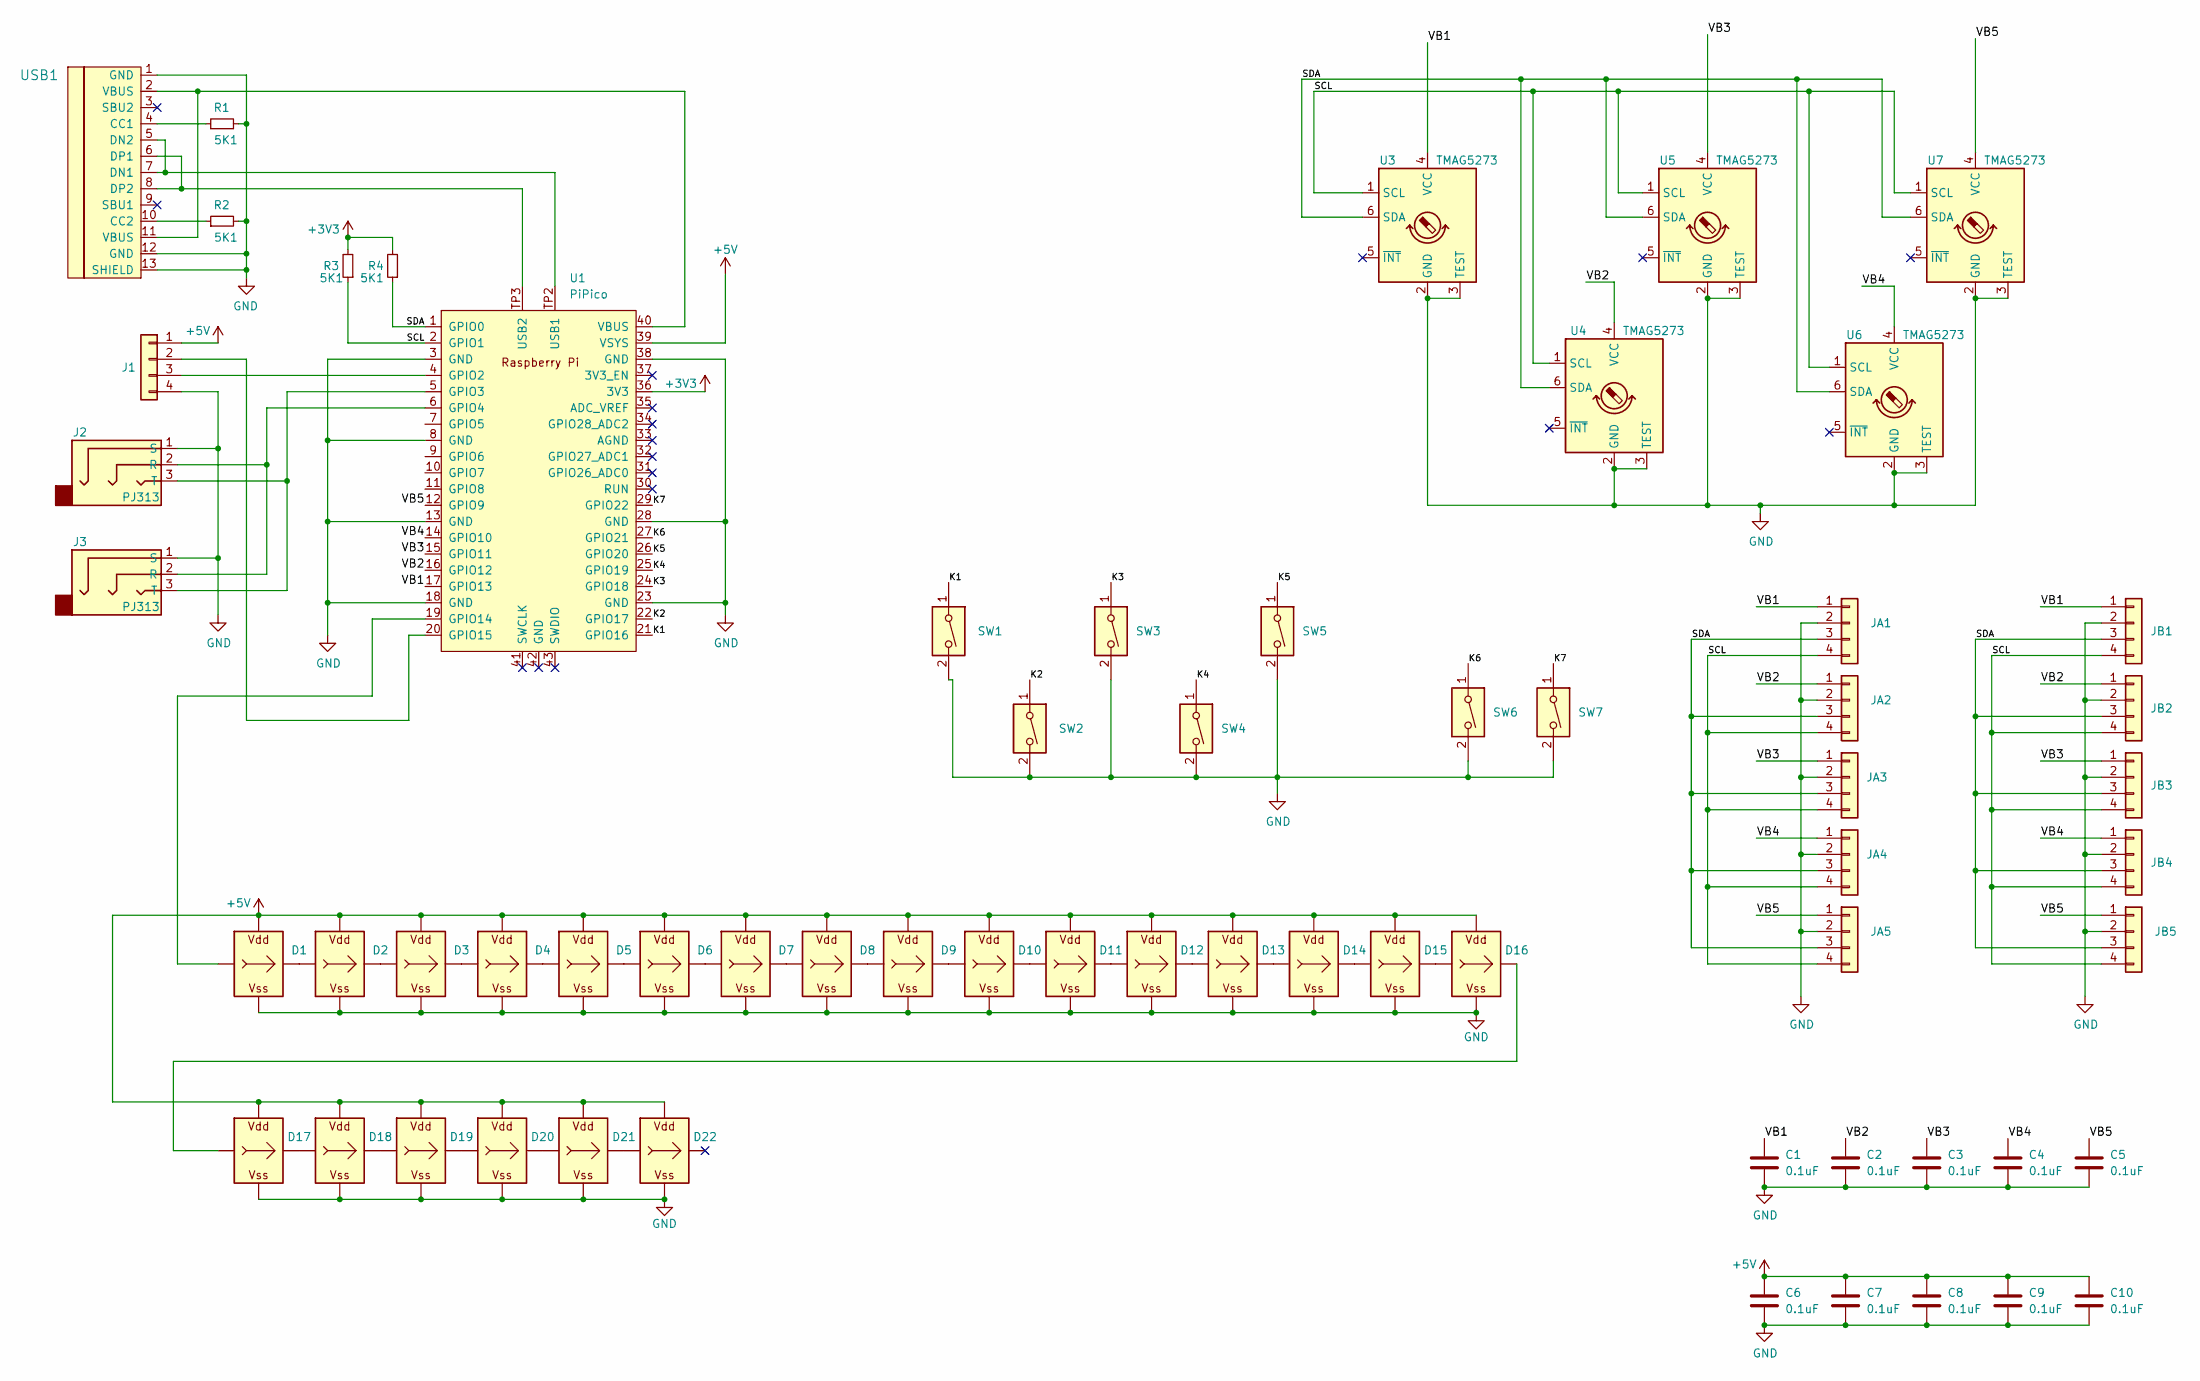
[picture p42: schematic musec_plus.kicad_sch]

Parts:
C1, C2, C3, C4, C5, C6, C7, C8, C9, C10: 0.1uF; C_0603_1608Metric_Pad1.08x0.95mm_HandSolder
D1, D2, D3, D4, D5, D6, D7, D8, D9, D10, D11, D12, D13, D14, D15, D16, D17, D18, D19, D20, D21, D22: WS2812B_Unified; WS2812B-2835
J1: Pedal; SH1.0_4P_Solder_Combo
J2, J3: PJ313
JA1, JA2, JA3, JA4, JA5: Conn_01x04; SH1.0_4P_Solder_Combo
JB1, JB2, JB3, JB4, JB5: Conn_01x04; SH1.0_4P_Solder_Combo
R1, R2, R3, R4: 5K1; R_0603_1608Metric_Pad0.98x0.95mm_HandSolder; LCSC C23186
SW1, SW2, SW3, SW4, SW5: SW_DIP_x01; Musec_ChocV1V2_x2_Combo
SW6, SW7: SW_DIP_x01; SW_Kailh_Choc_V1V2_1.00u_LED
U1: PiPico; RPi_Pico_SMD_Pins
U3, U4, U5, U6, U7: TMAG5273; TSOT-23-6_HandSoldering
USB1: U262-161N-4BVC11; HRO-TYPE-C-31-M-12-Assembly; LCSC C319148

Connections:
+3V3: R3.2, R4.2, U1.36 (3V3)
+5V: C6.1, C7.1, C8.1, C9.1, C10.1, D1.V (VDD), D2.V (VDD), D3.V (VDD), D4.V (VDD), D5.V (VDD), D6.V (VDD), D7.V (VDD), D8.V (VDD), D9.V (VDD), D10.V (VDD), D11.V (VDD), D12.V (VDD), D13.V (VDD), D14.V (VDD), D15.V (VDD), D16.V (VDD), D17.V (VDD), D18.V (VDD), D19.V (VDD), D20.V (VDD), D21.V (VDD), D22.V (VDD), J1.1, U1.39 (VSYS)
/K1: SW1.1, U1.21 (GPIO16)
/K2: SW2.1, U1.22 (GPIO17)
/K3: SW3.1, U1.24 (GPIO18)
/K4: SW4.1, U1.25 (GPIO19)
/K5: SW5.1, U1.26 (GPIO20)
/K6: SW6.1, U1.27 (GPIO21)
/K7: SW7.1, U1.29 (GPIO22)
/SCL: JA1.4, JA2.4, JA3.4, JA4.4, JA5.4, JB1.4, JB2.4, JB3.4, JB4.4, JB5.4, R3.1, U1.2 (GPIO1), U3.1 (SCL), U4.1 (SCL), U5.1 (SCL), U6.1 (SCL), U7.1 (SCL)
/SDA: JA1.3, JA2.3, JA3.3, JA4.3, JA5.3, JB1.3, JB2.3, JB3.3, JB4.3, JB5.3, R4.1, U1.1 (GPIO0), U3.6 (SDA), U4.6 (SDA), U5.6 (SDA), U6.6 (SDA), U7.6 (SDA)
/VB1: C1.1, JA1.1, JB1.1, U1.17 (GPIO13), U3.4 (VCC)
/VB2: C2.1, JA2.1, JB2.1, U1.16 (GPIO12), U4.4 (VCC)
/VB3: C3.1, JA3.1, JB3.1, U1.15 (GPIO11), U5.4 (VCC)
/VB4: C4.1, JA4.1, JB4.1, U1.14 (GPIO10), U6.4 (VCC)
/VB5: C5.1, JA5.1, JB5.1, U1.12 (GPIO9), U7.4 (VCC)
GND: C1.2, C2.2, C3.2, C4.2, C5.2, C6.2, C7.2, C8.2, C9.2, C10.2, D1.G (VSS), D2.G (VSS), D3.G (VSS), D4.G (VSS), D5.G (VSS), D6.G (VSS), D7.G (VSS), D8.G (VSS), D9.G (VSS), D10.G (VSS), D11.G (VSS), D12.G (VSS), D13.G (VSS), D14.G (VSS), D15.G (VSS), D16.G (VSS), D17.G (VSS), D18.G (VSS), D19.G (VSS), D20.G (VSS), D21.G (VSS), D22.G (VSS), J1.4, J2.1 (S), J3.1 (S), JA1.2, JA2.2, JA3.2, JA4.2, JA5.2, JB1.2, JB2.2, JB3.2, JB4.2, JB5.2, R1.2, R2.2, SW1.2, SW2.2, SW3.2, SW4.2, SW5.2, SW6.2, SW7.2, U1.3 (GND), U1.8 (GND), U1.13 (GND), U1.18 (GND), U1.23 (GND), U1.28 (GND), U1.38 (GND), U3.2 (GND), U3.3 (TEST), U4.2 (GND), U4.3 (TEST), U5.2 (GND), U5.3 (TEST), U6.2 (GND), U6.3 (TEST), U7.2 (GND), U7.3 (TEST), USB1.1 (GND), USB1.12 (GND), USB1.13 (SHIELD)
unnamed: D1.I (In), U1.19 (GPIO14)
unnamed: D1.O (Out), D2.I (In)
unnamed: D2.O (Out), D3.I (In)
unnamed: D3.O (Out), D4.I (In)
unnamed: D4.O (Out), D5.I (In)
unnamed: D5.O (Out), D6.I (In)
unnamed: D6.O (Out), D7.I (In)
unnamed: D7.O (Out), D8.I (In)
unnamed: D8.O (Out), D9.I (In)
unnamed: D9.O (Out), D10.I (In)
unnamed: D10.O (Out), D11.I (In)
unnamed: D11.O (Out), D12.I (In)
unnamed: D12.O (Out), D13.I (In)
unnamed: D13.O (Out), D14.I (In)
unnamed: D14.O (Out), D15.I (In)
unnamed: D15.O (Out), D16.I (In)
unnamed: D16.O (Out), D17.I (In)
unnamed: D17.O (Out), D18.I (In)
unnamed: D18.O (Out), D19.I (In)
unnamed: D19.O (Out), D20.I (In)
unnamed: D20.O (Out), D21.I (In)
unnamed: D21.O (Out), D22.I (In)
unnamed: J1.2, U1.20 (GPIO15)
unnamed: J1.3, U1.4 (GPIO2)
unnamed: J2.2 (R), J3.2 (R), U1.6 (GPIO4)
unnamed: J2.3 (T), J3.3 (T), U1.5 (GPIO3)
unnamed: U1.TP2 (USB1), USB1.5 (DN2), USB1.7 (DN1)
unnamed: U1.TP3 (USB2), USB1.6 (DP1), USB1.8 (DP2)
unnamed: U1.40 (VBUS), USB1.2 (VBUS), USB1.11 (VBUS)
unnamed: R1.1, USB1.4 (CC1)
unnamed: R2.1, USB1.10 (CC2)

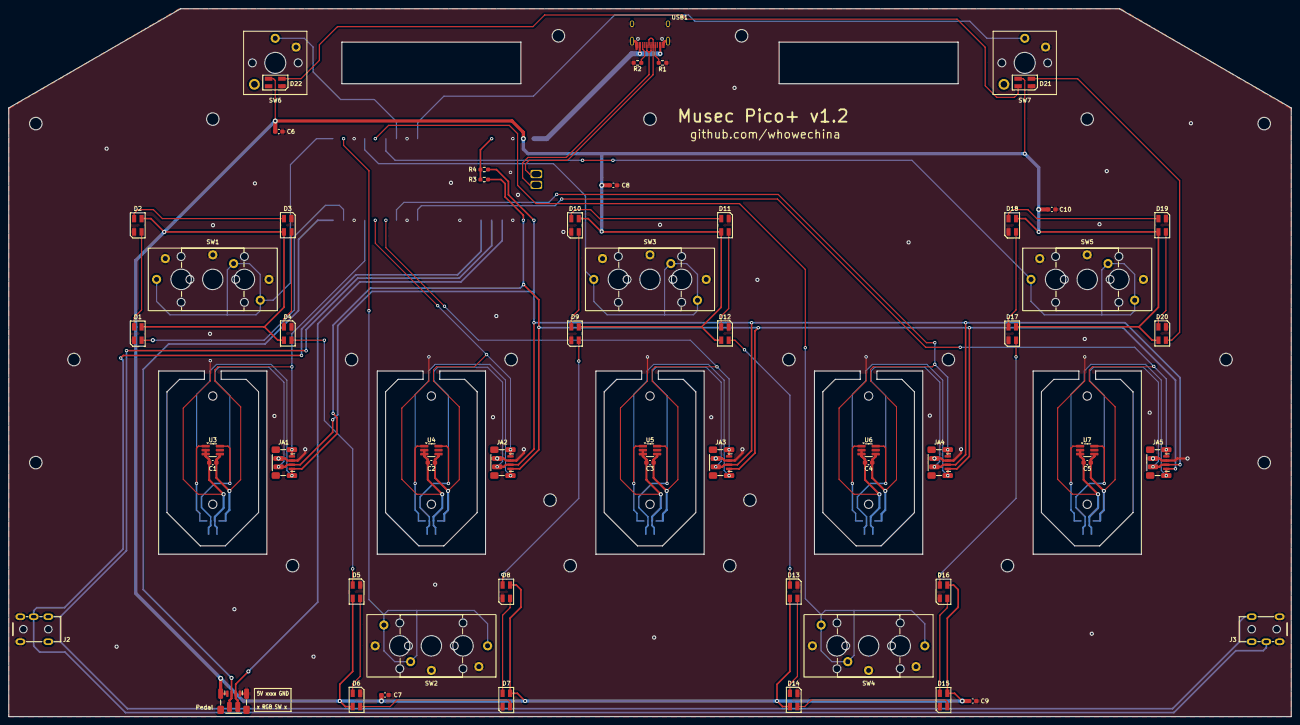
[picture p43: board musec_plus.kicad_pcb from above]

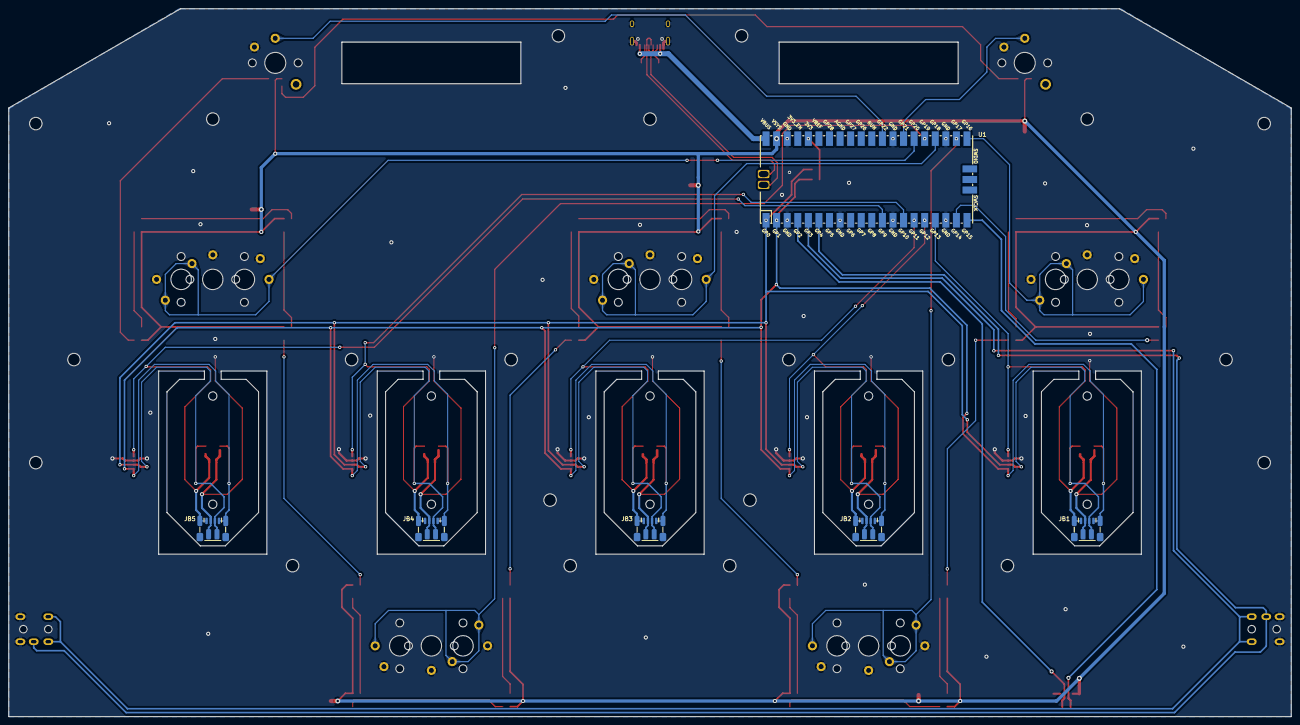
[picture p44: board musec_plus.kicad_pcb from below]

Board: 2 copper layers, 308.0 x 170.0 mm, 63 parts (6 on the bottom side), 48 nets.

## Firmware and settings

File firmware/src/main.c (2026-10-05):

/*
 * Controller Main
 * WHowe <github.com/whowechina>
 */

#include <stdlib.h>
#include <stdint.h>
#include <stdbool.h>

#include "pico/stdio.h"
#include "pico/stdlib.h"
#include "bsp/board.h"
#include "pico/multicore.h"
#include "pico/bootrom.h"

#include "hardware/gpio.h"
#include "hardware/sync.h"
#include "hardware/structs/ioqspi.h"
#include "hardware/structs/sio.h"

#include "tusb.h"
#include "usb_descriptors.h"

#include "board_defs.h"

#include "savedata.h"
#include "config.h"
#include "cli.h"
#include "commands.h"

#include "light.h"
#include "button.h"
#include "spin.h"

#define WHITE 0xffffff

static void run_lights()
{
    uint16_t button = button_read();

    uint32_t phase = time_us_32() >> 16;
    for (int i = 0; i < 5; i++) {
        uint32_t color = rgb32_from_hsv(phase + i * 35, 255, 128);
        if (button & (1 << i)) {
            color = WHITE;
        }
        light_set_spinner(i, color, false);
    }

    bool aux_down = button & 0x40;
    bool start_down = button & 0x20;

    light_set_start(start_down ? WHITE : rgb32(255, 10, 10, false), false);
    light_set_aux(aux_down ? WHITE : rgb32(180, 180, 10, false), false);

    uint32_t color = rgb32_from_hsv(phase + 175, 255, 128);

    bool int_pedal = button & 0x80;
    bool ext_pedal = button & 0x100;
    bool pedal = int_pedal || (ext_pedal ^ musec_runtime.ext_pedal_invert);

    light_set_pedal(0, pedal ? WHITE : color, false);
    light_set_pedal(1, pedal ? WHITE : color, false);
    light_set_pedal(2, pedal ? WHITE : color, false);
}

static void runtime_setup()
{
    uint16_t button = button_read();

    bool aux_down = button & 0x40;
    bool int_pedal = button & 0x80;

    if (aux_down && int_pedal) {
        musec_runtime.ext_pedal_invert = button & 0x100;
    }
}

static void core1_init()
{
    flash_safe_execute_core_init();
}

static void core1_loop()
{
    core1_init();

    while (1) {
        run_lights();
        light_update();
        cli_fps_count(1);
        sleep_us(700);
    }
}

struct __attribute__((packed)) {
    uint8_t buttons;
    uint8_t joy[6];
} hid_joy, hid_joy_sent;

static void gen_hid_report()
{
    uint16_t buttons = button_read();
    bool ext_pedal = buttons & 0x100;
    if (ext_pedal ^ musec_runtime.ext_pedal_invert) {
        buttons |= 0x80; // combine internal and external pedal
    }
    hid_joy.buttons = buttons & 0xff;
    for (int i = 0; i < 5; i++) {
        hid_joy.joy[i] = spin_units(i);
    }
}

static void hid_update()
{
    static uint64_t last_report_time = 0;

    gen_hid_report();

    if (tud_hid_ready()) {
        uint64_t now = time_us_64();
        if ((memcmp(&hid_joy, &hid_joy_sent, sizeof(hid_joy)) == 0) &&
            (now - last_report_time < 10000)) {
            return;
        }
        last_report_time = now;
        if (tud_hid_report(REPORT_ID_JOYSTICK, &hid_joy, sizeof(hid_joy))) {
            hid_joy_sent = hid_joy;
        }
    }
}

static void core0_loop()
{
    uint64_t next_frame = 0;
    while(1) {
        tud_task();

        cli_run();

        savedata_loop();
        cli_fps_count(0);

        button_update();
        spin_update();

        hid_update();

        runtime_setup();

        sleep_until(next_frame);
        next_frame += 1001;
    }
}

/* if certain key pressed when booting, enter update mode */
static void update_check()
{
    const uint8_t pins[] = BUTTON_DEF;
    int pressed = 0;
    for (int i = 0; i < count_of(pins); i++) {
        uint8_t gpio = pins[i];
        gpio_init(gpio);
        gpio_set_function(gpio, GPIO_FUNC_SIO);
        gpio_set_dir(gpio, GPIO_IN);
        gpio_pull_up(gpio);
        sleep_ms(1);
        if (!gpio_get(gpio)) {
            pressed++;
        }
    }

    if (pressed >= 4) {
        sleep_ms(100);
        reset_usb_boot(0, 2);
        return;
    }
}

static void detect_pedal_polarity()
{
    uint16_t buttons = button_read();
    musec_runtime.ext_pedal_invert = buttons & 0x100;
}

void init()
{
    sleep_ms(50);
    board_init();

    update_check();

    tusb_init();
    stdio_init_all();

    config_init();
    savedata_init(0xca44caac);

    light_init();
    button_init();
    spin_init();

    detect_pedal_polarity();

    cli_init("musec_pico>", "\n   << Musec Pico Controller >>\n"
                            " https://github.com/whowechina\n\n");
    
    commands_init();
}

int main(void)
{
    init();
    multicore_launch_core1(core1_loop);
    core0_loop();
    return 0;
}

// Invoked when received GET_REPORT control request
// Application must fill buffer report's content and return its length.
// Return zero will cause the stack to STALL request
uint16_t tud_hid_get_report_cb(uint8_t itf, uint8_t report_id,
                               hid_report_type_t report_type, uint8_t *buffer,
                               uint16_t reqlen)
{
    printf("Get from USB %d-%d\n", report_id, report_type);
    return 0;
}

// Invoked when received SET_REPORT control request or
// received data on OUT endpoint ( Report ID = 0, Type = 0 )
void tud_hid_set_report_cb(uint8_t itf, uint8_t report_id,
                           hid_report_type_t report_type, uint8_t const *buffer,
                           uint16_t bufsize)
{
    if ((report_id == REPORT_ID_LIGHTS) && (bufsize >= 27)) {
        for (int i = 0; i < 5; i++) {
            uint32_t color = rgb32(buffer[i * 3], buffer[i * 3 + 1], buffer[i * 3 + 2], false);
            light_set_spinner(i, color, true);
        }

        const uint8_t *title = buffer + 15;
        const uint8_t *pedal = buffer + 18;

        uint32_t title_color = rgb32(title[0], title[1], title[2], false);
        light_set_start(title_color, true);
        light_set_aux(title_color, true);
    
        for (int i = 0; i < 3; i++) {
            uint32_t color = rgb32(pedal[i * 3], pedal[i * 3 + 1], pedal[i * 3 + 2], false);
            light_set_pedal(i, color, true);
        }
    }
}

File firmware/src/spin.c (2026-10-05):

/*
 * The Spinning of Buttons
 * WHowe <github.com/whowechina>
 * 
 */

#include "spin.h"

#include <stdint.h>
#include <stdio.h>
#include <stdbool.h>
#include <stdlib.h>

#include "hardware/gpio.h"
#include "hardware/timer.h"
#include "hardware/pwm.h"

#include "config.h"
#include "board_defs.h"

#include "tmag5273.h"

static const uint8_t spin_enablers[] = SPIN_DEF;
const uint16_t FULL_SCALE = 360 * 16;

#define SPIN_NUM (count_of(spin_enablers))

void spin_init()
{
    gpio_init(BUS_I2C_SDA);
    gpio_set_function(BUS_I2C_SDA, GPIO_FUNC_I2C);
    gpio_pull_up(BUS_I2C_SDA);
    gpio_init(BUS_I2C_SCL);
    gpio_set_function(BUS_I2C_SCL, GPIO_FUNC_I2C);
    gpio_pull_up(BUS_I2C_SCL);

    if (musec_cfg->spin.fast_i2c) {
        i2c_init(BUS_I2C, BUS_I2C_FAST_FREQ);
    } else {
        i2c_init(BUS_I2C, BUS_I2C_FREQ);
    }

    for (int i = 0; i < SPIN_NUM; i++) {
        uint8_t ce = spin_enablers[i];
        gpio_init(ce);
        gpio_set_dir(ce, GPIO_OUT);
        gpio_put(ce, 1);
        sleep_us(1000);
        tmag5273_init(i, BUS_I2C);
        tmag5273_init_sensor();
    }
}

uint8_t spin_num()
{
    return SPIN_NUM;
}

bool spin_present(uint8_t index)
{
    if (index >= SPIN_NUM) {
        return false;
    }
    return tmag5273_is_present(index);
}

typedef struct {
    uint16_t angle;
    uint16_t old_angle;
    int queue;

    struct {
        bool active;
        bool dir;
        uint16_t speed_10x;
    } sim_spin; // software-simulated spin-down

    uint16_t last_speed;
    uint8_t stop_count;
    int8_t accel_count;

    uint8_t units;
} spin_ctx_t;

static spin_ctx_t spin_ctx[SPIN_NUM];

static int spin_get_delta(spin_ctx_t *ctx)
{
    int delta = ctx->angle - ctx->old_angle;
    if (delta > FULL_SCALE / 2) {
        delta -= FULL_SCALE;
    } else if (delta < -FULL_SCALE / 2) {
        delta += FULL_SCALE;
    }

    if (abs(delta) <= 8) {
        delta = 0;
    } else {
        ctx->old_angle = ctx->angle;
    }

    return delta;
}

static void spin_move(spin_ctx_t *ctx, int delta)
{
    ctx->queue += delta;

    int step = FULL_SCALE / musec_cfg->spin.units_per_turn;
    int num_steps = ctx->queue / step;

    ctx->units += num_steps;
    ctx->queue -= step * num_steps;
}

static int spin_suppress(spin_ctx_t *ctx, int delta)
{
    if (musec_cfg->spin.suppress.threshold == 0) {
        ctx->sim_spin.active = false;
        ctx->stop_count = 0;
        return delta;
    }

    if (abs(delta) >= musec_cfg->spin.suppress.threshold) {
        // threshold exceeded
        ctx->sim_spin.active = true;
        ctx->stop_count = 0;
        ctx->accel_count = 0;
        ctx->sim_spin.dir = (delta > 0);
        ctx->sim_spin.speed_10x = abs(delta) * 10;
    }

    if (ctx->sim_spin.active) {
        if ((abs(delta) > 20) && ((delta > 0) != ctx->sim_spin.dir)) {
            // inverted direction detected
            ctx->sim_spin.active = false;
            ctx->stop_count = 0;
            ctx->last_speed = abs(delta);
            return delta;
        }

        if (delta == 0) {
            ctx->stop_count++;
            if (ctx->stop_count >= 4) {
                // physical stop detected
                ctx->sim_spin.active = false;
                ctx->last_speed = abs(delta);
                return delta;
            }
        } else {
            ctx->stop_count = 0;
        }

        ctx->accel_count += (abs(delta) > ctx->last_speed) ? 1 : -1;
        if (ctx->accel_count >= 5) {
            // external force detected (natural irregularities filtered)
            ctx->sim_spin.active = false;
        } else if (ctx->accel_count < 0) {
            ctx->accel_count = 0;
        }
    }

    ctx->last_speed = abs(delta);

    if (ctx->sim_spin.active) {
        // spin-down
        int decay = musec_cfg->spin.suppress.decay;
        ctx->sim_spin.speed_10x =
            (ctx->sim_spin.speed_10x > decay) ? ctx->sim_spin.speed_10x - decay : 0;

        // simulated speed instead of actual delta
        delta = (ctx->sim_spin.dir ? ctx->sim_spin.speed_10x : -ctx->sim_spin.speed_10x) / 10;
    }

    return delta;
}

static void spin_proc(int index)
{
    spin_ctx_t *ctx = &spin_ctx[index];

    int delta = spin_get_delta(ctx);

    int final_delta = spin_suppress(ctx, delta);

    spin_move(ctx, final_delta);
}

void spin_update()
{
    static int index = 0;

    tmag5273_use(index);
    uint16_t raw = tmag5273_read_angle();
    bool invert = musec_cfg->spin.reversed & (1 << index);
    int angle = invert ? FULL_SCALE - raw : raw;

    spin_ctx[index].angle = angle;

    spin_proc(index);

    index = (index + 1) % SPIN_NUM;
}

uint16_t spin_read(uint8_t index)
{
    if (index >= SPIN_NUM) {
        return 0;
    }
    return spin_ctx[index].angle;
}

uint16_t spin_units(uint8_t index)
{
    if (index >= SPIN_NUM) {
        return 0;
    }
    return spin_ctx[index].units;
}

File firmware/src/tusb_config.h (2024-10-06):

/*
 * The MIT License (MIT)
 *
 * Copyright (c) 2019 Ha Thach (tinyusb.org)
 *
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
 */

#ifndef _TUSB_CONFIG_H_
#define _TUSB_CONFIG_H_

#ifdef __cplusplus
extern "C" {
#endif

//--------------------------------------------------------------------
// COMMON CONFIGURATION
//--------------------------------------------------------------------

// defined by board.mk
#ifndef CFG_TUSB_MCU
#error CFG_TUSB_MCU must be defined
#endif

// RHPort number used for device can be defined by board.mk, default to port 0
#ifndef BOARD_DEVICE_RHPORT_NUM
#define BOARD_DEVICE_RHPORT_NUM 0
#endif

// RHPort max operational speed can defined by board.mk
// Default to Highspeed for MCU with internal HighSpeed PHY (can be port
// specific), otherwise FullSpeed
#ifndef BOARD_DEVICE_RHPORT_SPEED
#if (CFG_TUSB_MCU == OPT_MCU_LPC18XX || CFG_TUSB_MCU == OPT_MCU_LPC43XX ||   \
     CFG_TUSB_MCU == OPT_MCU_MIMXRT10XX || CFG_TUSB_MCU == OPT_MCU_NUC505 || \
     CFG_TUSB_MCU == OPT_MCU_CXD56)
#define BOARD_DEVICE_RHPORT_SPEED OPT_MODE_HIGH_SPEED
#else
#define BOARD_DEVICE_RHPORT_SPEED OPT_MODE_FULL_SPEED
#endif
#endif

// Device mode with rhport and speed defined by board.mk
#if BOARD_DEVICE_RHPORT_NUM == 0
#define CFG_TUSB_RHPORT0_MODE (OPT_MODE_DEVICE | BOARD_DEVICE_RHPORT_SPEED)
#elif BOARD_DEVICE_RHPORT_NUM == 1
#define CFG_TUSB_RHPORT1_MODE (OPT_MODE_DEVICE | BOARD_DEVICE_RHPORT_SPEED)
#else
#error "Incorrect RHPort configuration"
#endif

#ifndef CFG_TUSB_OS
#define CFG_TUSB_OS OPT_OS_NONE
#endif

// CFG_TUSB_DEBUG is defined by compiler in DEBUG build
// #define CFG_TUSB_DEBUG           0

/* USB DMA on some MCUs can only access a specific SRAM region with restriction
 * on alignment. Tinyusb use follows macros to declare transferring memory so
 * that they can be put into those specific section. e.g
 * - CFG_TUSB_MEM SECTION : __attribute__ (( section(".usb_ram") ))
 * - CFG_TUSB_MEM_ALIGN   : __attribute__ ((aligned(4)))
 */
#ifndef CFG_TUSB_MEM_SECTION
#define CFG_TUSB_MEM_SECTION
#endif

#ifndef CFG_TUSB_MEM_ALIGN
#define CFG_TUSB_MEM_ALIGN __attribute__((aligned(4)))
#endif

//--------------------------------------------------------------------
// DEVICE CONFIGURATION
//--------------------------------------------------------------------

#ifndef CFG_TUD_ENDPOINT0_SIZE
#define CFG_TUD_ENDPOINT0_SIZE 64
#endif

//------------- CLASS -------------//
#define CFG_TUD_HID 1
#define CFG_TUD_CDC 1
#define CFG_TUD_MSC 0
#define CFG_TUD_MIDI 0
#define CFG_TUD_VENDOR 0

// HID buffer size Should be sufficient to hold ID (if any) + Data
#define CFG_TUD_HID_EP_BUFSIZE 64

#define CFG_TUD_VENDOR            0

// HID buffer size Should be sufficient to hold ID (if any) + Data
#define CFG_TUD_HID_EP_BUFSIZE    64

// CDC FIFO size of TX and RX
#define CFG_TUD_CDC_RX_BUFSIZE   (TUD_OPT_HIGH_SPEED ? 512 : 128)
#define CFG_TUD_CDC_TX_BUFSIZE   (TUD_OPT_HIGH_SPEED ? 512 : 128)

// CDC Endpoint transfer buffer size, more is faster
#define CFG_TUD_CDC_EP_BUFSIZE   (TUD_OPT_HIGH_SPEED ? 512 : 128)

#ifdef __cplusplus
}
#endif

#endif /* _TUSB_CONFIG_H_ */

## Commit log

2024-09-26 PCB work starts
    [530470310.stp, 8002A.step, Button Cap.step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]
2024-09-27 PCB progress 70%
    [Housing - PCB.dxf, SM04B-SRSS-TB.STEP, musec_pico.kicad_pcb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]
2024-09-28 PCB almost done (95%)
    [musec_pico.kicad_pcb, musec_pico.kicad_sch]
2024-09-28 PCB v1.0
    [Housing - PCB.dxf, musec_pico.kicad_pcb, musec_pico.kicad_sch]
2024-10-05 Pedal button
2024-10-07 PCB v1.1 to support pedal
    [TRS Jack PJ-313.stp, musec_pico.kicad_pcb, musec_pico.kicad_sch]
2024-10-09 PCB v1.2 (internal pedal connector and light)
    [musec_pico.kicad_pcb, musec_pico.kicad_sch]
2024-10-09 Remove usb report debug print
2024-10-10 PCB V1.21, larger thru-holes for PJ313
    [musec_pico.kicad_pcb]
2024-10-10 Move main PCB to a sub-folder
    [530470310.stp, 8002A.step, Button Cap.step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]
2024-10-10 Pedal board v1.0
    [Button_Pedal - PCB.dxf, musec_pedal.kicad_pcb, musec_pedal.kicad_sch]
2024-10-13 Pedal polarity reset at runtime1
    [main.c]
2024-10-13 Spin reverse setting works
    [main.c, spin.c]
2024-10-14 PCB v1.22 for better PJ313 footprint
    [musec_pico.kicad_pcb]
2024-10-15 PCB v1.23 better footprints
    [musec_pico.kicad_pcb, musec_pico.kicad_sch]
2024-10-16 3D Print files
    [musec_pico_aux.stl, musec_pico_bearing_fixer.stl, musec_pico_bottom.stl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]
2024-10-16 Add more magnet option
2024-10-16 Shaft lub and limiter
2024-10-17 Better screw holes
    [musec_pico_bearing_fixer.stl, musec_pico_lever.stl]
2024-10-17 Pedal PCB v1.1 (fix stabilizer position)
    [Button_Pedal - PCB.dxf, musec_pedal.kicad_pcb]
2024-10-17 Pedal PCB v1.2 (more accurate holes)
    [Button_Pedal - PCB.dxf, musec_pedal.kicad_pcb]
2024-10-18 Stronger lever support
    [musec_pico_bottom.stl]
2024-10-23 PCB v1.3 (a little bit easier soldering)
    [musec_pico.kicad_pcb, musec_pico.kicad_sch]
2024-11-11 Change link to JST sockets
    The current link is for vertical sockets when it appears as though right angle ones are intended.
2024-11-12 More accurate SH1.0 connector description
2024-11-16 Provide instructions for bearing prep.
    The uxcell bearings from Amazon in the US come lubed with a heavy oil that prevents free spinning, so I thought I'd give some suggestions on how to improve the bearings you get instead of resorting to finding other ones. This gif illustrates the difference between a stock and relubed bearing: https://imgur.com/a/FHSBLm4
2024-11-16 Add note about acetone
    Acetone should only be used on all metal bearings since it's a polar solvent.
2024-11-19 Bearing oil replacement guide in CN
2025-02-06 Stronger lever
    [musec_pico_lever.stl]
2025-02-09 Better shaft slits (avoid break)
2025-03-16 Slower I2C clock for some slow sensors
2025-05-04 Move original PCB to pico folder
    [530470310.stp, 8002A.step, Button Cap.step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]
2025-05-04 Start PCB work for Musec Pico Plus
    [530470310.stp, 8002A.step, Button Cap.step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]
2025-05-05 Musec Pico+ PCB v1.0
    [Musec Pico+ - PCB.dxf, musec_plus.kicad_pcb, musec_plus.kicad_sch]
2025-05-17 Guide for Musec Pico+
    [musec_pico+_bearing_fixer.stl, musec_pico+_keycap.3mf, musec_pico+_lever.stl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]
2025-05-17 Musec Pico+ PCB v1.01
    [Musec Pico+ - PCB.dxf, musec_plus.kicad_pcb]
2025-05-17 Fix bearing models for Musec Pico+
2025-05-17 Correct steel shaft length for Musec Pico+
2025-06-07 Fix shaft end screw sink for Musec+
    [musec_pico+_shaft_end_5mm.stl]
2025-06-12 Bigger pads for Musec Pico+
2025-10-16 Pedal v1.21, better SH1.0 footprint
    [musec_pedal.kicad_pcb]
2025-11-25 Explicit I2C Pull-ups
    [musec_pico.kicad_pcb, musec_pico.kicad_sch, musec_plus.kicad_pcb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]
2025-11-27 I2C speed options
2026-01-22 pedal pcb v1.22, finetune
    [musec_pedal.kicad_pcb]
2026-09-04 PCB V1.2, add pedal TRS ring option
    [musec_plus.kicad_pcb, musec_plus.kicad_sch]
2026-10-04 Switch to newer savedata module
